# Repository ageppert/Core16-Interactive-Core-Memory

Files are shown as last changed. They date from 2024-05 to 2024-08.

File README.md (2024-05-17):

# Core-16-Interactive-Core-Memory-Badge
Weave your own 16 bits of core memory over the top of LEDs to interact with directly using a magnetic wand. This project shares the same codebase as Core64. 

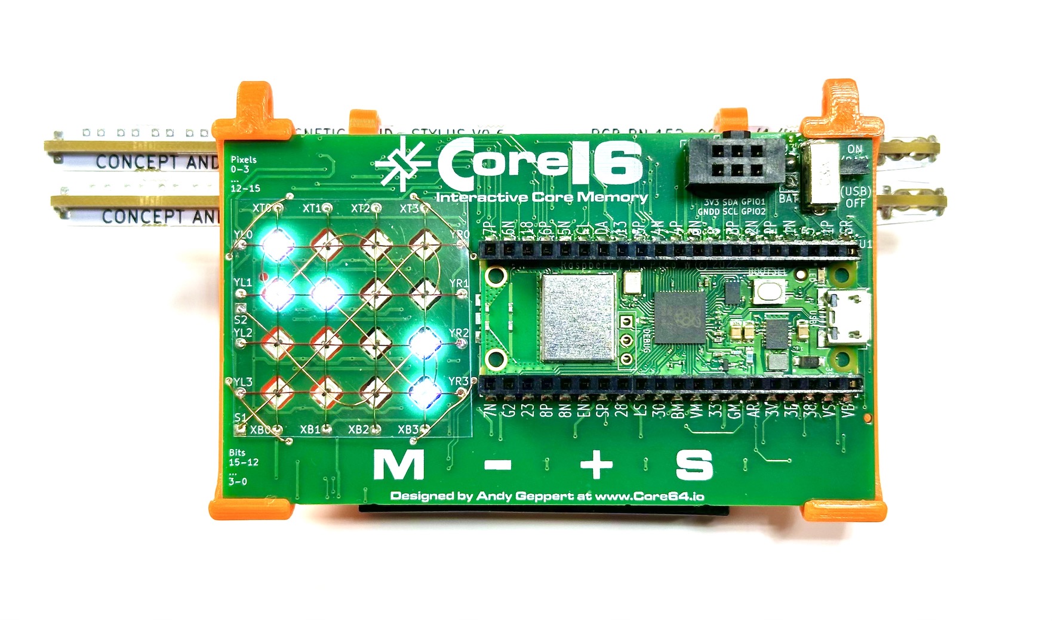
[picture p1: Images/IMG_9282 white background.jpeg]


Purchase: https://www.Core64.io

Follow this project at: https://hackaday.io/project/191834-core16-interactive-core-memory-made-smaller

You are in the hardware development repository. Firmware is at https://github.com/ageppert/Core64/releases

# Hardware Version History (latest on top)

v0.2 Logic Board - First production batch

v0.1 Logic Board - Prototype Build

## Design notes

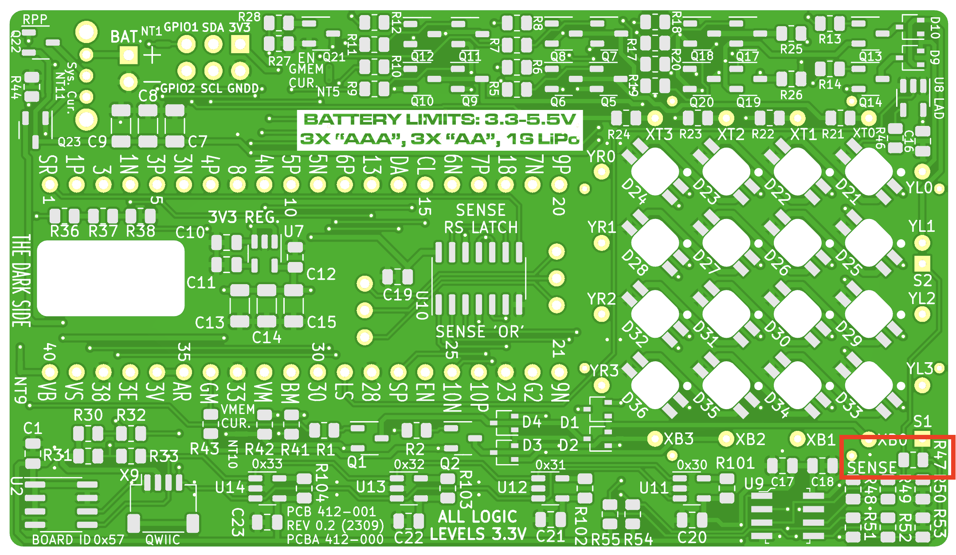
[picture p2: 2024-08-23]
Electronic Design/Core16_LB_V0.2 Schematic and Renders/Core16_LB_V0.2_Render_Back R47.png

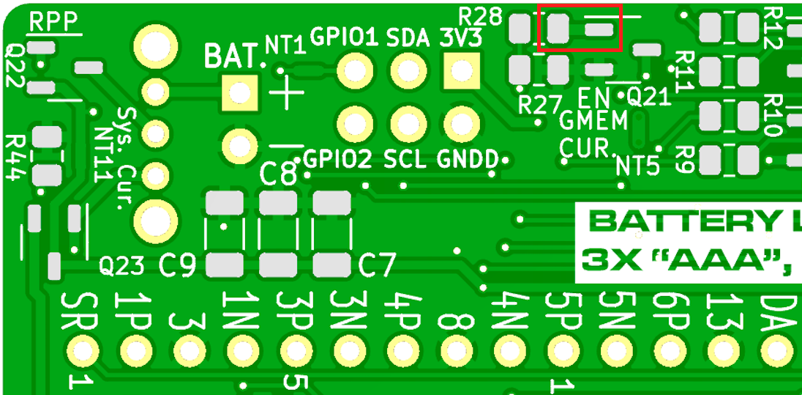
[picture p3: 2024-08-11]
Electronic Design/Core16_LB_V0.2 Schematic and Renders/CM_EN Q21 R28.png

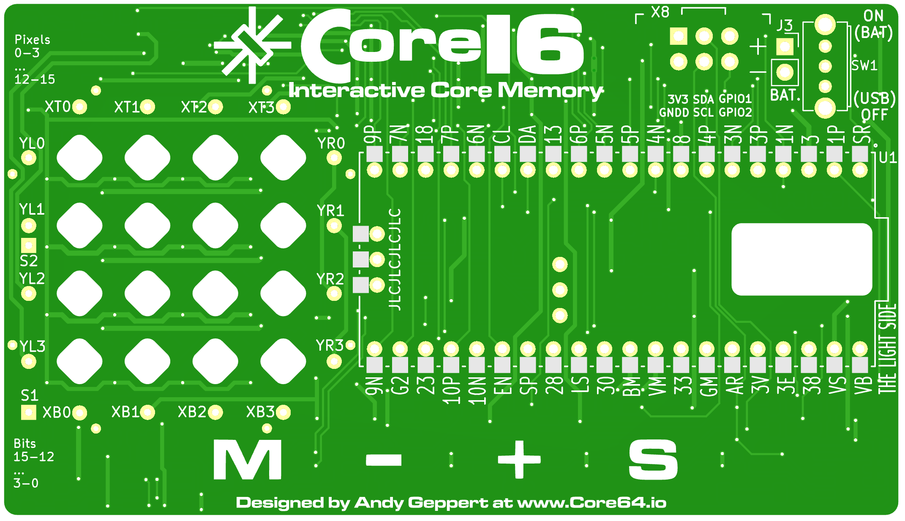
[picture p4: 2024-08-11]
Electronic Design/Core16_LB_V0.2 Schematic and Renders/Core16_LB_V0.2_Render_Front.png

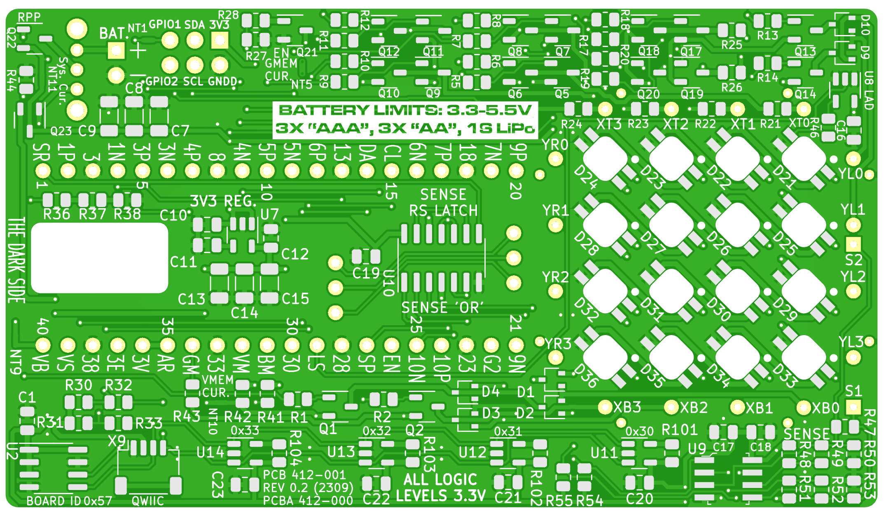
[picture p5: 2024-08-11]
Electronic Design/Core16_LB_V0.2 Schematic and Renders/Core16_LB_V0.2_Render_Back.png

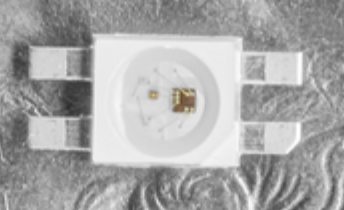
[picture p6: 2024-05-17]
Datasheets/LED REV MOUNT SK6812 light side.png

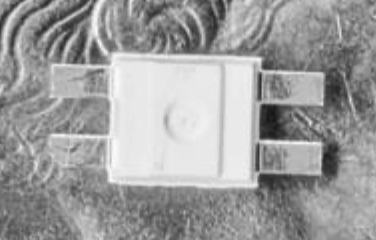
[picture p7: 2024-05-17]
Datasheets/LED REV MOUNT SK6812 dark side.png

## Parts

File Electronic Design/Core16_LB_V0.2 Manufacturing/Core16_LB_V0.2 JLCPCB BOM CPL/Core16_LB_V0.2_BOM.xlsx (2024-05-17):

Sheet: Core16_LB_BOM
Line | Description | Designators | Package | Qty | Manufacturer | MPN | Notes | Substitute | Customer Provided? | Vendor | Vendor PN | Manufacturer(Secondary) | MPN(Secondary) | VENDOR (SECONDARY) | VEMDOR P/N (SECONDARY)
1 | Capacitor 0805 0.1uF | C1, C16, C17, C19-C23 | 0805 | 8 | Cheaper to buy 1000 |  | Prefer X7R, X5R OK too. | YES | NO
2 | Capacitor 1206 220uF | C7-C9, C13-C15 | 1206 | 6 |  |  | Prefer X7R, X5R OK too. | YES | NO
3 | Capacitor 0805 1uF | C10, C12 | 0805 | 2 |  |  | Prefer X7R, X5R OK too. | YES | NO
4 | Capacitor 0805 0.01uF | C11 | 0805 | 1 |  |  | Prefer X7R, X5R OK too. | YES | NO
5 | Capacitor 0805 10uF | C18 | 0805 | 1 |  |  | Prefer X7R, X5R OK too. | YES | NO
6 | DIODE ARRAY SCHOTTKY 30V BAT54CW | D1, D3, D9 | SOT-323 | 3 | Diodes Inc. | BAT54CW-7-F |  | NO | NO | DIGI-KEY | BAT54CW-FDITR-ND
7 | DIODE ARRAY SCHOTTKY 30V BAT54AW | D2, D4, D10 | SOT-323 | 3 | Diodes Inc. | BAT54AW-7-F |  | NO | NO | DIGI-KEY | BAT54AW-FDITR-ND
8 | NEOPIXEL REVERSE MOUNT RGB LED SK6812 | D21-D36 | 3.10mm L x 2.70mm W | 16 | DONGGUAN OPSCO OPTOELECTRONICS | SK6812-E | EEK. Just one manufacturer I know of! Sold through Digi-Key, Mouser, and Adafruit. | NO | NO | DIGI-KEY | 1528-4960-ND |  |  | MOUSER | 485-4960
9 | TRANS MMBT4403LT1G PNP 40V 0.6A SOT23 | Q1, Q5, Q7, Q9, Q11, Q13, Q17, Q19 | SOT-23 | 8 | ON Semiconductor | MMBT4403LT1G | Cheaper to buy 1000 | NO | NO | DIGI-KEY | MMBT4403LT1GOSCT-ND | Diodes Inc. | MMBT4403-7-F
10 | TRANS MMBT4401LT1G NPN 40V 0.6A SOT23 | Q2, Q6, Q8, Q10, Q12, Q14, Q18, Q20 | SOT-23 | 8 | ON Semiconductor | MMBT4401LT1G | Cheaper to buy 1000 | NO | NO | DIGI-KEY | MMBT4401LT1GOSCT-ND | Diodes Inc. | MMBT4401-7-F
11 | MOSFET NVTR4503NT1G_NMOS_GSD N-CHNL GSD LOW RDS(ON) | Q21 | SOT-23 | 1 | ON Semiconductor | NVTR4503NT1G |  | NO | NO | DIGI-KEY | NVTR4503NT1GOSTR-ND | Infineon Technologies | IRLML2030TRPBF
12 | MOSFET SL3401A P-Channel 30V 4.2A 2V @ 250uA 50mŒ© @ 4.2A,10V 1.4W SOT-23 | Q22, Q23 | SOT-23 | 2 | Micro Commercial Co | SL3401A-TP |  | NO | NO | DIGI-KEY | 353-SL3401A-TPTR-ND
13 | RES 470 OHM 10% | R1, R2, R5-R14, R17-R20, R28, R46 | 0805 | 18 |  |  | Any as long as tolerance matched or better | YES | NO
14 | RES 6.8 OHM 1/8W 5% | R21-R26 | 0805 | 6 |  |  | Any as long as tolerance matched or better | YES | NO
15 | RES 10K OHM 10% | R27, R36-R38, R44, R101-R104 | 0805 | 9 | Cheaper to buy 1000 |  | Any as long as tolerance matched or better | YES | NO
16 | RES 1.2K OHM 10% | R30, R31, R54, R55 | 0805 | 4 |  |  | Any as long as tolerance matched or better | YES | NO
17 | RES 68 OHM 10% | R32, R33 | 0805 | 2 |  |  | Any as long as tolerance matched or better | YES | NO
18 | RES 10K OHM 10% | R41-R43 | 0805 | 3 |  |  | Any as long as tolerance matched or better | YES | NO
19 | RES 1.5K OHM 1% | R50, R53 | 0805 | 2 |  |  | Any as long as tolerance matched or better | YES | NO
20 | RES 1.8K OHM 1% | R48, R51 | 0805 | 2 |  |  | Any as long as tolerance matched or better | YES | NO
21 | RES 11 OHM 1% | R49, R52 | 0805 | 2 |  |  | Any as long as tolerance matched or better | YES | NO
22 | IC EEPROM M24C02-RMN 2KBIT I2C 400KHZ 8SOIC | U2 | 8-SOIC | 1 | STMicroelectronics | M24C02-WMN6TP |  | NO | NO | DIGI-KEY | 497-8552-2-ND
23 | Fixed 3.3V 300mV @ 300mA SOT-23-5 Dropout Regulators(LDO) RoHS | U7 | SOT23-5 | 1 | SG Micro | SGM2007-3.3XN5_TR |  | NO | NO | DIGI-KEY | 296-TPS7A0533PDBVRTR-ND | TI | TPS7A0533PDBVR
24 | IC BUF NON-INVERT 5.5V SOT23-5 | U8 | SOT23-5 | 1 | Texas Instruments | SN74LV1T125DBVR |  | NO | NO | DIGI-KEY | 296-37172-2-ND | OnSemi | M74VHC1GT125DT1G
25 | IC COMPARATOR LM393 LP DUAL 8-SOIC | U9 | 8-SOIC | 1 | STMicroelectronics | LM393DT |  | NO | NO | DIGI-KEY | 497-1593-2-ND | Rohm | LM393DR
26 | IC GATE SN74HC02DR NOR 4CH 2-INP 14SOIC | U10 | 14-SOIC | 1 | Texas Instruments | SN74HC02DR |  | NO | NO | DIGI-KEY | 296-1188-2-ND
27 | Si7210 Series I2C Hall Effect Magnetic Position and Temperature Sensor 1 | U11 | SOT23-5 | 1 | Silicon Labs | SI7210-B-00-IV | Similar to the others, but has specific I2C bus address | NO | NO | DIGI-KEY | 336-4068-ND
28 | Si7210 Series I2C Hall Effect Magnetic Position and Temperature Sensor 2 | U12 | SOT23-5 | 1 | Silicon Labs | SI7210-B-02-IV | Similar to the others, but has specific I2C bus address | NO | NO | DIGI-KEY | 336-SI7210-B-02-IV-ND
29 | Si7210 Series I2C Hall Effect Magnetic Position and Temperature Sensor 3 | U13 | SOT23-5 | 1 | Silicon Labs | SI7210-B-03-IV | Similar to the others, but has specific I2C bus address | NO | NO | DIGI-KEY | 336-SI7210-B-03-IV-ND
30 | Si7210 Series I2C Hall Effect Magnetic Position and Temperature Sensor 4 | U14 | SOT23-5 | 1 | Silicon Labs | SI7210-B-04-IV | Similar to the others, but has specific I2C bus address | NO | NO | DIGI-KEY | 336-4056-ND
31 | JST_SH_SM04B-SRSS-TB_1x04 QWIIC Connector right angle | X9 | SM04B-SRSS-TB | 1 | JST | SM04B-SRSS-TB | Not on Mouser, digi only | NO | NO | DIGI-KEY | 455-SM04B-SRSS-TBTR-ND
 |  | Need 5 more sk6812-E |  | 117

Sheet: Sheet1
Part # | Mouser # | Mfr. # | Manufacturer | Description | Order Qty. | Price (USD) | Ext.: (USD)
C1, C16, C17, C19-C23 | 187-CL21B104KAFNNNE | CL21B104KAFNNNE | Samsung Electro-Mechanics | Multilayer Ceramic Capacitors MLCC - SMD/SMT 100nF+/-10% 25V X7R 0805 | 805 | $0.009 | $7.24
C10, C12 | 187-CL21B105KAFNNNE | CL21B105KAFNNNE | Samsung Electro-Mechanics | Multilayer Ceramic Capacitors MLCC - SMD/SMT 1uF+/-10% 25V X7R 20 0805 | 205 | $0.021 | $4.31
C18 | 187-CL21B106KOQNNNG | CL21B106KOQNNNG | Samsung Electro-Mechanics | Multilayer Ceramic Capacitors MLCC - SMD/SMT 10uF+/-10% 16V X7R 2 0805 | 105 | $0.061 | $6.41
D1, D3, D9 | 621-BAT54CW-F | BAT54CW-7-F | Diodes Incorporated | Schottky Diodes & Rectifiers 30V 200mW | 301 | $0.098 | $29.50
D2, D4, D10 | 621-BAT54AW-F | BAT54AW-7-F | Diodes Incorporated | Schottky Diodes & Rectifiers 30V 200mW | 301 | $0.106 | $31.91
D21-D36 | 485-4960 | 4960 | Adafruit | Adafruit Accessories NeoPixel Reverse Mount RGB LEDs - 10 Pack of SK6812-E | 140 | $2.95 | $413.00
Q1, Q5, Q7, Q9, Q11, Q13, Q17, Q19 | 863-MMBT4403LT1G | MMBT4403LT1G | onsemi | Bipolar Transistors - BJT 600mA 40V PNP | 1002 | $0.03 | $30.06
Q2, Q6, Q8, Q10, Q12, Q14, Q18, Q20 | 863-MMBT4401LT1G | MMBT4401LT1G | onsemi | Bipolar Transistors - BJT 600mA 60V NPN | 1002 | $0.032 | $32.06
Q21 | 863-NVTR4503NT1G | NVTR4503NT1G | onsemi | MOSFET Single N-Channel Power MOSFET 30V, 2.5A, 110mohm Automotive Version of the NTR4503N | 101 | $0.183 | $18.48
Q22, Q23 | 833-SL3401A-TP | SL3401A-TP | Micro Commercial Components (MCC) | Schottky Diodes & Rectifiers P-Ch -30V 12Vgs 1.5W -4.4A | 202 | $0.186 | $37.57
R1, R2, R5-R14, R17-R20, R28, R46 | 660-RK73H2ATTD4700F | RK73H2ATTD4700F | KOA Speer | Thick Film Resistors - SMD 1/4W 470 OHM 1% | 1810 | $0.007 | $12.67
R21-R26 | 660-RK73H2ATTD6R80F | RK73H2ATTD6R80F | KOA Speer | Thick Film Resistors - SMD 1/4W 6.8 OHM 1% | 610 | $0.011 | $6.71
R27, R36-R38, R44, R101-R104 | 660-RK73H2ATTD1002F | RK73H2ATTD1002F | KOA Speer | Thick Film Resistors - SMD 1/4W 10K OHM 1% | 910 | $0.007 | $6.37
R30, R31, R41-R43, R54, R55 | 660-RK73H2ATTD1201F | RK73H2ATTD1201F | KOA Speer | Thick Film Resistors - SMD 1/4W 1.2K OHM 1% | 710 | $0.01 | $7.10
R32, R33 | 660-RK73H2ATTD68R0F | RK73H2ATTD68R0F | KOA Speer | Thick Film Resistors - SMD 1/4W 68 OHM 1% | 205 | $0.01 | $2.05
R48, R51 | 660-RK73H2ATTD1801F | RK73H2ATTD1801F | KOA Speer | Thick Film Resistors - SMD 1/4W 1.8K OHM 1% | 205 | $0.01 | $2.05
R49, R52 | 660-RK73H2ATTD11R0F | RK73H2ATTD11R0F | KOA Speer | Thick Film Resistors - SMD 1/4W 11 OHM 1% | 205 | $0.01 | $2.05
R50, R53 | 660-RK73H2ATTD1501F | RK73H2ATTD1501F | KOA Speer | Thick Film Resistors - SMD 1/4W 1.5K OHM 1% | 205 | $0.01 | $2.05
U10 | 595-SN74HC02DR | SN74HC02DR | Texas Instruments | Logic Gates Quad 2-Input | 101 | $0.194 | $19.59
U11 | 634-SI7210-B-00-IVR | Si7210-B-00-IVR | Silicon Laboratories | Board Mount Hall Effect / Magnetic Sensors I2C programmable Hall effect magnetic sensor with push-pull output | 101 | $1.01 | $102.01
U12 | 634-SI7210-B-02-IV | Si7210-B-02-IV | Silicon Laboratories | Board Mount Hall Effect / Magnetic Sensors I2C programmable Hall effect magnetic sensor with push-pull output | 101 | $0.901 | $91.00
U13 | 634-SI7210-B-03-IV | Si7210-B-03-IV | Silicon Laboratories | Board Mount Hall Effect / Magnetic Sensors I2C programmable Hall effect magnetic sensor with push-pull output | 101 | $0.806 | $81.41
U14 | 634-SI7210-B-04-IVR | Si7210-B-04-IVR | Silicon Laboratories | Board Mount Hall Effect / Magnetic Sensors I2C programmable Hall effect magnetic sensor with push-pull output | 101 | $0.828 | $83.63
U2 | 511-M24C02-WMN6TP | M24C02-WMN6TP | STMicroelectronics | EEPROM EEPROM S I2C 2K | 101 | $0.133 | $13.43
U8 | 595-SN74LV1T125DBVR | SN74LV1T125DBVR | Texas Instruments | Translation - Voltage Levels SGL Pwr Supply SGL Buffer GATE | 101 | $0.316 | $31.92
U9 | 511-LM393DT | LM393DT | STMicroelectronics | Analog Comparators Lo-Pwr Dual Voltage SOIC-8 | 101 | $0.268 | $27.07
U7 | 595-TLV75533PDBVR | TLV75533PDBVR | Texas Instruments | IC REG LINEAR 3.3V 500MA SOT23-5 | 101 | $0.201 | $20.30
 | Digi #
C7-C9, C13-C15 | 490-GRM31CR60J227ME11KCT-ND | GRM31CR60J227ME11K | Murata Electronics | CAP CER 220UF 6.3V X5R 1206 | 605 | $0.343 | $207.21
D21-D36 | 1528-4960-ND | 4960 | Ada Fruit | NeoPixel | 15 | $2.950 | $44.25
X9 | 455-SM04B-SRSS-TBTR-ND | SM04B-SRSS-TBTR-ND |  | JST_SH_SM04B-SRSS-TB_1x04 QWIIC Connector right angle | 100 | $0.427 | $42.66
 |  |  |  |  |  |  | $1416.08
 |  |  |  | I always buy a few extra parts for caps, etc in case one is damaged, or flies into oblivion during construction. :-)
 |  |  |  | Will still need 50 more neopixels from Ada, or other source
 |  |  |  | This price doesn't include shipping or tax from Digi, just the parts for the moment.
 |  |  |  | Still missing the regulator too.
 |  |  |  | Andy's Notes updating V0.1 to V0.2 BOM
 |  |  |  | Added U7 3V3 REG as the TI part you suggested up in the Mouser section. Removed from Digikey.
 |  |  |  | Removed C11 since it is not needed with the new TI Regulator.
 |  |  |  | Corrected R21-26 from 6.8K to 6.8 OHM
 |  |  |  | Move R41-43 out of the group in the line above (10K) to 1K2, corrected quantities on both lines
 |  |  |  | Corrected C1, C16, C17, C19-C23 (8x) quantity from 1010 to 805

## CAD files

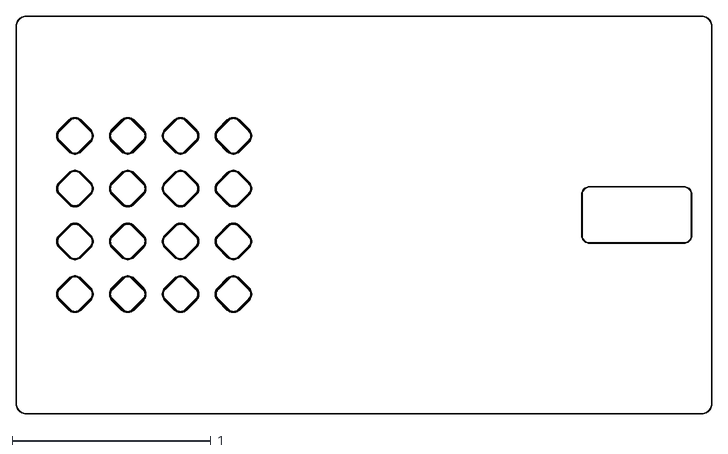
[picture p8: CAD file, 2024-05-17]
Electronic Design/Core16_LB_V0.2 Manufacturing/Core16_LB-Edge_Cuts.dxf
3.50 x 2.00

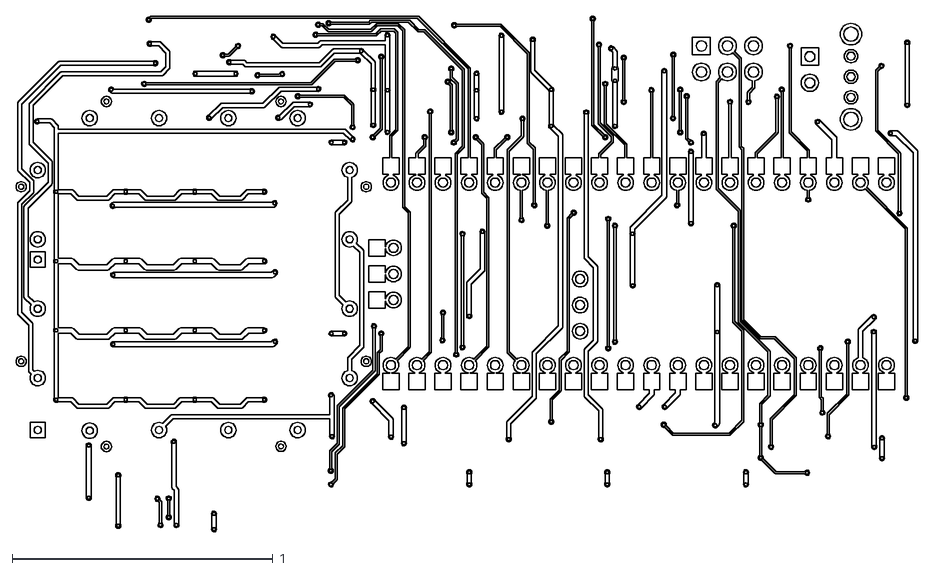
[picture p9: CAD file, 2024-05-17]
Electronic Design/Core16_LB_V0.2 Manufacturing/Core16_LB-F_Cu.dxf
3.46 x 1.98

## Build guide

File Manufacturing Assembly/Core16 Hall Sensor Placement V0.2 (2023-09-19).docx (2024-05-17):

Core16 Hall Sensor Placement V0.2 (2023-09-19)

The hall sensors are installed on the Back Side (AKA The Dark Side). Each one has only one position it can be in to work correctly because they all have unique I2C IDs. Once they are removed from the packaging you can no longer identify which is which.

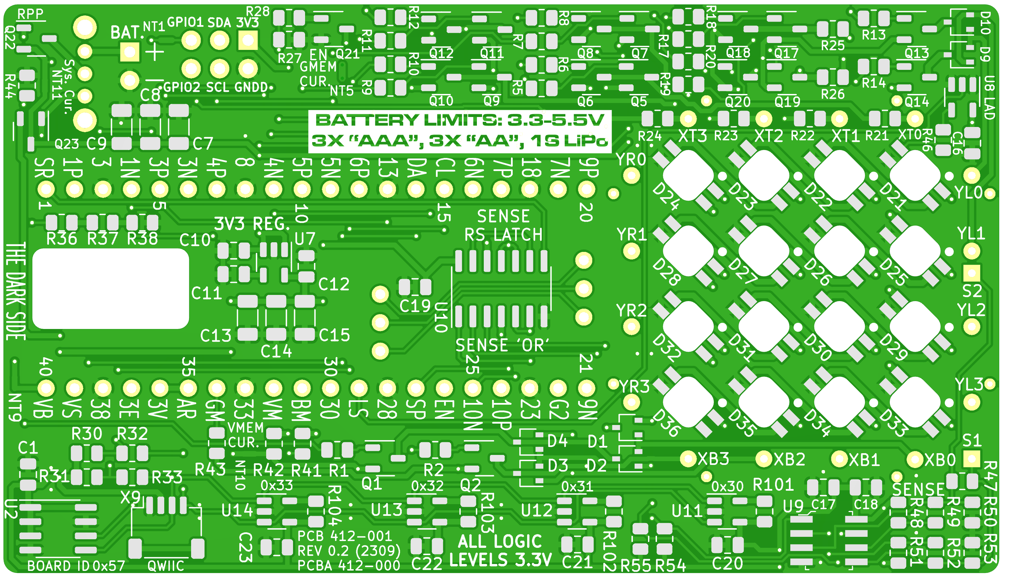
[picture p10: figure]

S + - M

4 3 2 1

P/N SI7210-B- -04 -03 -02 -00

For reference, this is the Front Side (AKA The Light Side)

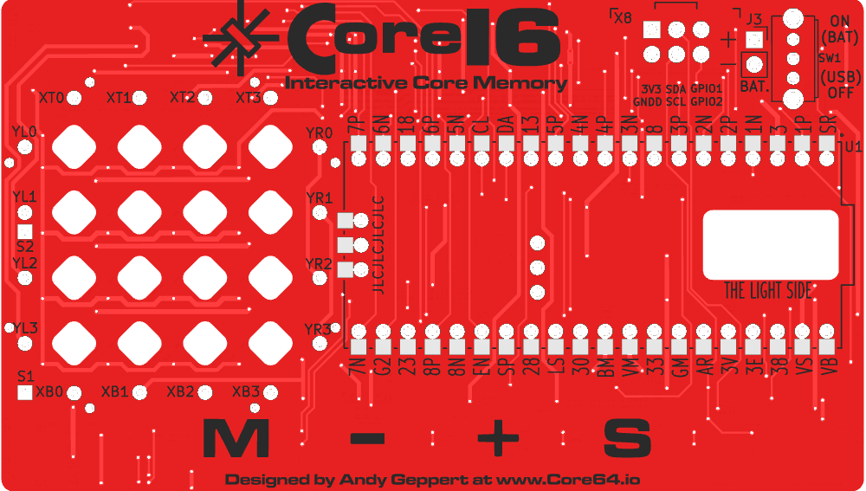
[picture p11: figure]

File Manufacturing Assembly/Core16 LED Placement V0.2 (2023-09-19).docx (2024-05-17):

Core16 LED Placement V0.2 (2023-09-19)

SK6812Mini-E LEDs are installed on the Back Side (AKA The Dark Side)

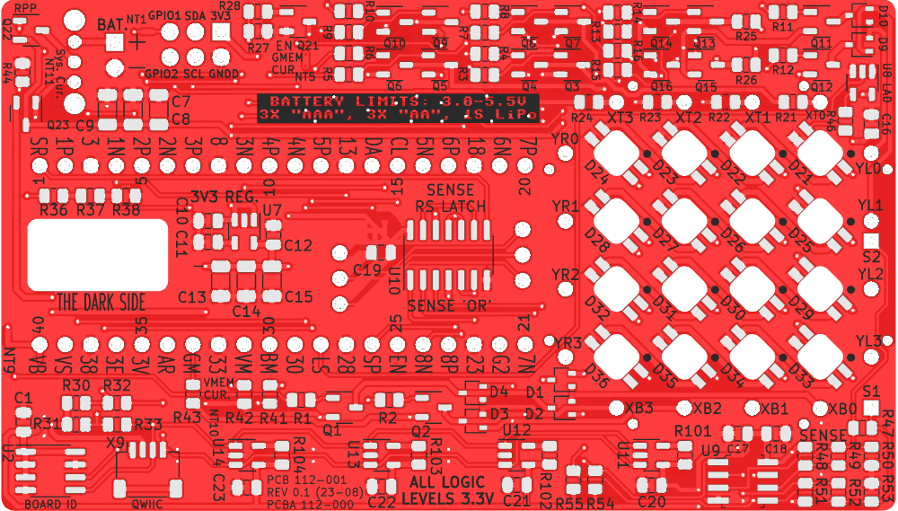
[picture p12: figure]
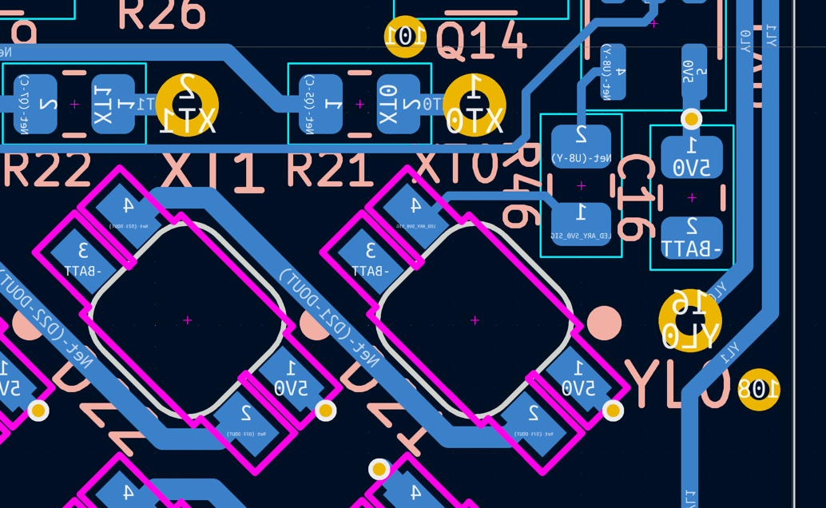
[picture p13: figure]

DOUT

DIN

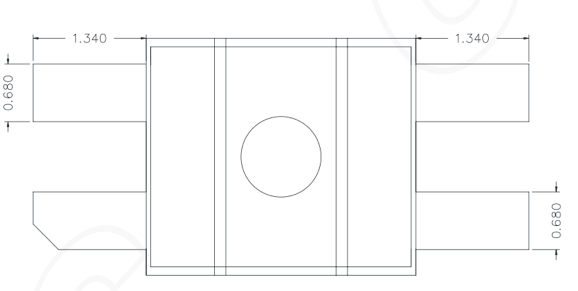
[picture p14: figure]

5V0

GND

CENTERED IN THE CUTOUT

These LEDs are serially connected which means if any LED in the chain is missing or damaged, all the LEDs downstream will not work. When testing the assembly process, always start with D21.

For reference, this is how they look on the Front Side (AKA The Light Side)

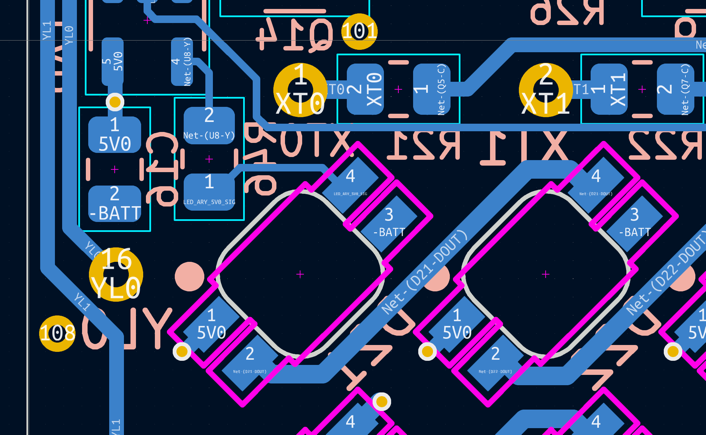
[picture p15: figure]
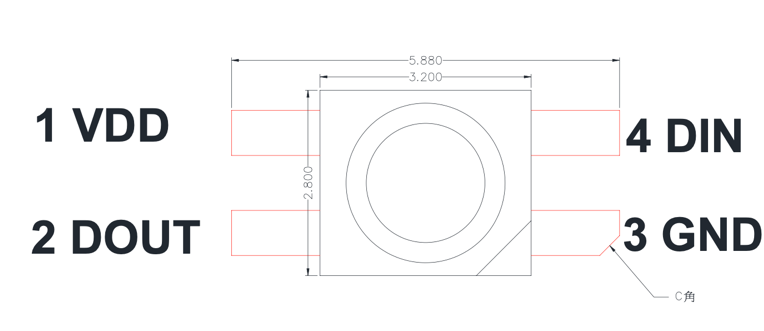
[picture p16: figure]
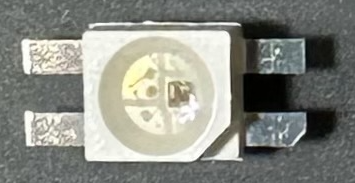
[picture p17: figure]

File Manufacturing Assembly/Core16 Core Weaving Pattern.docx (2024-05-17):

Core16 Core Weaving Pattern (2023-10-08)

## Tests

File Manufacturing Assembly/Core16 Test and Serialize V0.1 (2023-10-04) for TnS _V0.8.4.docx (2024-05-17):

Core16 Test and Serialize

Document V0.1 (2023-10-04) goes with firmware “Core16_TnS _V0.8.4.uf2”

Program the Raspberry Pi Pico with latest Test and Serialize (TnS) firmware. See Appendix A.

(1) Write Serial Number with thin sharpie or sticker on the back of the Core16 Logic Board.

OK to use last 3 digits only. Write between U7 and U10. This batch of 100 starts at S/N 300006 and goes to 300105.

(2) Program the Core16 Board ID EEPROM with the Serial Number

Start with power off, clamp Core16 Logic Board in the test fixture, power on.

Connect with Serial Terminal at 115200 8N1. LEDs may flash brightly.

Start-up sequence determines if Board ID EEPROM is present and blank.

CORE16: Use 's' command to set last three digits of 300xxx serial number.

Examples: S 6<ENTER> or S 105<ENTER>

Core16 restarts immediately after a valid entry.

(3) Verify I2C Bus Devices are present and

I2C Bus Scan results

Verify I2C SCAN 5 items are present:

Device found at address 0x30 (SI7210-B-01, Hall Sensor 1)

Device found at address 0x31 (SI7210-B-02, Hall Sensor 2)

Device found at address 0x32 (SI7210-B-03, Hall Sensor 3)

Device found at address 0x33 (SI7210-B-04, Hall Sensor 4)

Device found at address 0x57 (EEPROM BOARD ID)

Depending on the test fixture configuration, there may also be another device if the OLED is connected:

Device found at address 0x3C (SSD1306,DigisparkOLED)

(4) Verify power supply is good

INFO DISPLAY: Verify INFO section voltages 5V0 Rail = 5.0 ± 0.3 and 3V3 Rail = 3.3 ± 0.1

(5) Test Core Memory Matrix Driver Circuitry

NOT AVAILABLE IN SIMPLE TEST FIXTURE WHEN CORES ARE NOT INSTALLED.

If S/N is >= 300006, it will automatically jump to MODE_CORE_TEST_MANY (#31)

Use the magnetic stylus on the core memory to make sure all pixels respond by lighting up.

(6) Test Hall Sensors

Touch + with stylus to move to next mode, MODE_HALL_TEST (#32)

Verify one LED lights for each magnetic button. With each stylus touch of magnetic button, one of the four corresponding lower row LEDs will illuminate.

(7) Test LEDs

Dwell 2 seconds on “+” magnetic button to go to next MODE_LED_TEST_ALL_RGB (#33).

Verify all LEDs are illuminated in RED, GREEN, BLUE sequence.

Power off and remove Core16 from test fixture.

END OF TEST

# APPENDIX A: PROGRAMMING A PICO

Program the Raspberry Pi Pico with latest Test and Serialize (TnS) firmware

Start with power off.

Hold button on Pico, connect Pico USB to computer, release button.

Pico enumerates as Mass Storage device. RPI-RP2 or similar.

Open Mass Storage device and drag-n-drop “Core16_TnS _V0.8.4.uf2” into first level.

File copies over, Mass Storage device disappears, Pico restarts and runs the new firmware.

In normal operation, the Pico LED blinks in heartbeat pattern when powered on and streams information through serial port.

End with power off.

# APPENDIX B: IMPLEMENTATION NOTES

case MODE_START_EEPROM

If LogicBoardTypeGet returns UNKNOWN, set MODE_MANUFACTURING_EEPROM_FACTORY_WRITE and break right before LED and Buttons are set-up.

case MODE_START_SEQUENCE_COMPLETE

If LogicBoardTypeGet is Core16 and S/N is between 300004 and 300105,

One more INFO so it’s close to the bottom of the screen.

Change Mode to MODE_CORE_TEST_MANY

case MODE_MANUFACTURING_EEPROM_FACTORY_WRITE

Serial interaction:

Mfg mode splash

Core16 expecting S/N 300006 to 300105.

Request last three digits of S/N.

Add Command Line Handler for undocumented command “S” followed by a number.

The largest value that can be handled with atoi is 65535.

Verify between 6 and 105.

Convert that number back to STRING of three characters to write to EEPROM.

Write everything to EEPROM.

INFO

Prompt user “is it correct Y/N?”

If yes, Set mode to MODE_START_POWER_ON

If no, ask for last 3 digits

If S/N 300001 to 300005 then HWV = 0.1.0 and manufacturer is JLCPCB.

If S/N 300006 to 300105 then HWV = 0.2.0 and manufacturer is TexElec.

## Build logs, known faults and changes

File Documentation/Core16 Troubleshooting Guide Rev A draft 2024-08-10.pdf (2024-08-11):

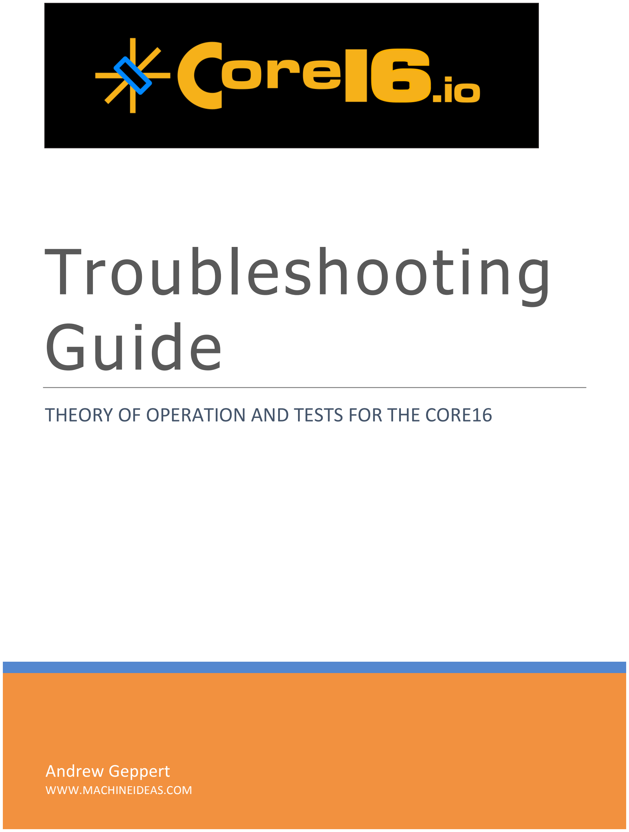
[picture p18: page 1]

# Andrew Geppert

### WWW.MACHINEIDEAS.COM

# Troubleshooting Guide

# THEORY OF OPERATION AND TESTS FOR THE CORE16

Core16 Troubleshooting Guide | www.Core16.io | 2

## 1. TABLE OF CONTENTS

## 2. Version History of This Guide

Revision | Description | Author | Date
A | First draft | Andy Geppert | 2024-08-10

The project homepage for this product is at www.Core16.io, which may still point to www.Core64.io.
The latest version of documentation is at https://github.com/ageppert/Core16-Interactive-Core-Memory.
The latest version of firmware is shared with Core64 and Core64c at https://github.com/ageppert/Core64/releases. Concept and design by Andy Geppert at www.MachineIdeas.com.

## 3. Important Cautions and Warnings

Beware the ESD monster!

Pico refers the Raspberry Pi Pico or Pico W which is should have all 40 castellated vias solder to the Core16 Logic Board.

Logic Board refers to the Core16 Logic Board.

Oscilloscope voltages are generally not accurate and have a surprising amount of error tolerance compared to a good multimeter. Oscilloscope voltages are more for reference and looking at signal shapes. Don’t be thrown off if a normal voltage is listed in the documentation here, and your scope is off by several tenths of a volt. Similarly, how much do you trust your multimeter? Just keep this general advice in mind and don’t get too hung up on voltage level accuracy.

Continuity checks should be done with a good multimeter. Press the probe tips into the solder joint to get through the cruft.

Use flux for soldering, but also, clean it off when you are done soldering.

These caution symbols point out important things to help ensure your assembly goes smoothly!

## 4. Introduction

This guide steps through the functionality of the Logic Board for Core16. Each functional section is reviewed, in sequence form power on through full operation of all cores and associated LEDs.

You do not need to proceed through the guide in sequence. Use your intuition to jump in where you think it makes sense. For instance, if you are confident you have power and the correct firmware installed, and the LEDs always on but unresponsive to the magnetic stylus, jump to the section “Core Matrix Row and Column Drivers.”

Since each of the Core16 Logic Boards go through a complete functional test before shipping to customers, the most likely problem areas are where the customer completes final assembly steps. In order of most frequent to least frequent:
- Core Matrix solder joints
- Core Sense Wire solder joints
- Core weaving pattern
- Solder connections between the Pico castellated vias and the Logic Board
- Battery and power switch connections
- Stylus magnetism weak due to excessive soldering heat

Carefully check all of those items to make sure they are all done well, and all connections that you made have good continuity.

Still, it could be that something has been damaged elsewhere on the Logic Board. Perhaps by mishandling, or damaging components adjacent to the outer edges of the Logic Board, or around the perimeter of the Core Matrix area. Visually inspect those areas carefully.

When installing the Core16 into the plastic carrier frame, insert the left edge of the board by sliding it into the plastic clips on the left. Then carefully snap the right edge plastic clips up around the right edge of the board. The reasoning is that the components on the back-side of the left edge/corners of the board are more fragile than the ones on the right edge/corners.

When removing the Core16 from the plastic carrier frame, carefully un-snap the right edge first. Then slide the left edge out of the plastic clips.

The following sections are organized in the functional sequence of the Core16 system. That is:
- Power Supply
- Microcontroller – the Pico W
- Serial Port
- I2C Bus Interface
- EEPROM for Board ID
- Info Query
- Core Matrix Wiring – the part you complete, which is the most likely source of issues
- Core Matrix Enable
- Core Matrix Row and Column Drivers
- Core Signal Sense
- Core Signal Output Latch
- Magnetic Stylus
- RGB LEDs
- Hall Sensors
- SAO OLED (optional)
- SAO and QWIIC ports (optional accessories)

## 5. Theory of Operation

All modes of operation with the Cores, LEDs and Magnetic Stylus are similar. Each Core in the matrix is written to with a pulsed electromagnetic field created along the length of the row and column wires. Where the two address wires intersect the core, the combined (aka coincident) magnetic field is strong enough to magnetize the wire in a clockwise or counter-clockwise orientation. Each orientation is defined as 1 or 0. If the orientation has been changed by the magnetic field created in the address wires, a small voltage will be induced into the sense wire. That voltage is detected by differential op-amps in the sense circuit, and latched into simple dual-NOR gate latch. If this occurs, the firmware detects that the core state was changed, the core will then be reset to the opposite state, and the firmware reports the value of that core bit. This information is used to illuminate the corresponding LED when the core is set to 1, or extinguish the LED if the core is 0.

## 6. Schematic and PCB Layout

Reference: https://github.com/ageppert/Core16-Interactive-Core-Memory/tree/master/Electronic%20Design/Core16_LB_V0.2%20Schematic%20and%20Renders

Schematic
The schematic is organized into functional sections which correspond to the sections of this guide.

PCB Layout
The PCB layout is fairly tight, and doesn’t follow the schematic blocks perfectly, but it attempts to lump functional elements together in the same area.
TO DO: Block diagram sections of schematic connected to rendering of the back of the board to make navigation easier.

## 7. Symptoms and Test Table

Failure Symptoms and likely causes
If all of the LEDs are on, there is a problem common to the whole matrix. The sense wire and circuit are common to the whole matrix.
The core memory enable CM_EN signal is common to the whole matrix.
Overview
After power on, the 4x4 matrix of LEDs should show three symbols in a row, in RED: C, 16, and the hysteresis flux symbol.
Then it will move to scrolling text “I [heart] CORE16”.
After that that, several more multicolor symbols will be displayed and it will return to scrolling text.

During scrolling text, the cores are actually being used as screen RAM. Interaction with the magnetic stylus should alter the state of the LEDs in the scrolling text mode.

In the other mode, displaying symbols, the cores are NOT being used, and just the LEDs are being controlled.

Beginning with the power sources. The Core16 may be powered from a battery pack or micro USB cable. To

SYMPTOM | TEST STARTING POINT | ASSUMPTIONS
Nothing happens when I connect the USB Cable. | Power Supply | No power.
All I see is an Green LED blinking on the Pico W. | | No firmware.

The serial port responds, but nothing shows on the RGB LEDs

Some symbols displayed correctly, but instead of scrolling text, all LEDs are on, fading through a rainbow of colors. None of the cores/LEDs respond to the magnetic stylus in any mode. | Info Query, and subsequent sections. | Power from USB is good. Firmware is installed. Serial connection established

## 8. Power Supply

Quick Test
With only USB power, switch in OFF (USB) position, ground at SAO port GND, verify
- 5.0V at VB pin 40 on Pico W (aka 5V_USB, PICO_VBUS)
- 4.9V at VS pin 39 on Pico W (aka PICO_VSYS)
- 3.3V at SAO port 3V3 pin
- 3.3V at U9 LM393 Dual Op-amp pin 8
- 3.3V at U10 74HC02 Quad NOR pin 14

Overview
Beginning with the power sources. The Core16 may be powered from a battery pack or micro USB cable. To simplify troubleshooting, use just the USB cable and leave the battery pack disconnected or remove the batteries. This will provide enough current to the Core16 Logic Board for troubleshooting, and enables serial communications for testing and diagnostics. Additionally, the computer USB ports are current limited.

For consistent troubleshooting, keep the USB cable connected, and enter mode 30 “SPECIAL/CORE TEST ONE.” The measurements included in the subsections below are made with the Core16 in this mode. Similar results are expected with the battery, but since you are troubleshooting the operation of the cores, you are unlikely to be able to navigate the menu with the cores/stylus. Thus, all testing is done with USB power.

Ground Reference for Measurements
Use the GND pin of the SAO port as your ground reference.

Battery Power on Back of Logic Board
The default configuration supports three “AAA” alkaline cells. Nominally, they supply 4.5V. Absolutely do not exceed 5.5V by trying something like a 2S LiPo. This will destroy the 3.3V Regulator.

If you suspect a short-circuit in the system, limit the current with a current limited power supply or resistor in series with the battery pack to the positive terminal of the Logic Board.

USB Power into Pico on Front of Logic Board
Connect the Pico to your computer with the MicroUSB cable. This supplies a clean 5V and it is conveniently current limited by the computer USB power manager. Unless there is something completely short-circuited on the Core16 Logic Board, the current limiting can be considered a nice feature.

The quality of USB cables varies significantly. The cable included in the kit has been tested to work well. Other cables may have excessive resistance, or by power only, without data signals. Make sure you are using a good USB cable with power AND data. Measure the voltage at the Pico connection to the Logic Board at Pin 40 labeled VB for VBUS. A range of 4.5 to 5.0V is normal.

It can be helpful to have a switched USB Hub between the computer and the Core16 so you can press a button to turn off the Core16 (to reset it) instead of unplugging the fragile Mico USB connection to the Core16. For example:

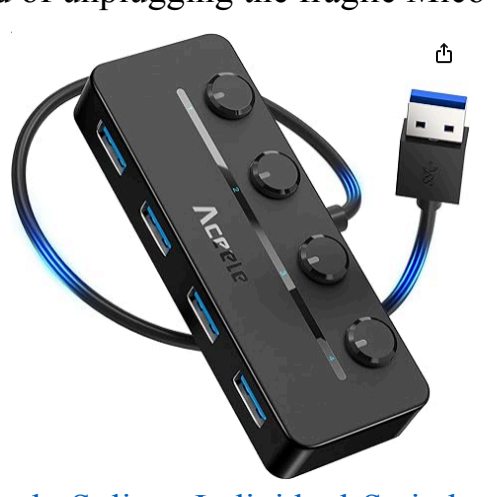
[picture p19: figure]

https://www.amazon.com/Aceele-Splitter-Individual-Switches-Portable/dp/B0CBTN686G/

Some USB hubs keep the serial connection (USB Data) connected and only interrupt the USB 5V power line.

Power Switch
The ON (BAT) position selects the battery as the source of power. It does NOT disconnect USB power if a USB cable is connected to the Pico because power is supplied downstream directly to the 5V0 rail of the Logic Board. The USB power bypasses the switch and reverse polarity protection circuit.

The OFF (USB) position selects the USB port as the source of power. It disconnects the battery power. If a USB cable is not connected, it effectively cuts all power to the Logic Board.

RPP - Reverse Polarity Protection
The protection is for the battery pack wires, which are soldered in near the power switch. If the wires are soldered into the wrong positions, or the battery cells are reversed, it prevents the Logic Board from receiving reverse polarity and protects it from damage.

+V Switched = 5V0
USED FOR:
- RGB LEDS
- 3V3 REGULATOR
This is a carry over from the Core64/c kits, which allow battery pack voltages greater than 5V, and include a 5V0 Regulator. In Core16, the voltage at this +VSW and 5V0 are equal, and will by 5V or less. Three capacitors are provided as bulk storage to smooth out power draw fluctuations from the RGB LEDs and the demands of the 3V3 Regulator. Despite the label of 5V0, the voltage will be between 3.5V and 5.0V normally.

3V3 Regulator
USED FOR:
- SYSTEM LOGIC
- CORE MATRIX DRIVER
- CORE MATRIX SENSE
- HALL SENSORS
- SAO AND QWIIC PORTS
The 3V3 Regulator creates a stable 3.3V source for all of the logic in the system, and the core memory.

Core Matrix Power
Three capacitors provide bulk storage to help hold up the 3V3 rail during the current surges used to write to the cores. Each row and column wire used to access a core is around 200-250 mA. When combined, this is a substantial 400-500mA draw on the 3V3 rail.

Core Matrix Enable
The Core Memory Enable CM_EN signal activates the Core Matrix FET which connects the entire Core Driver circuit GMEM to ground. This is used as a sort of a safety mechanism. During experimentation with firmware and control algorithms, you might inadvertently create a situation where the Core Matrix Drive Transistors are shorting the 3V3 to ground. By only activating CM_EN for a brief moment after the transistors are configured, this limits potential damage to the drive circuit. Generally, the 3V3 regulator save the components by kicking in a current limiting feature which will cause the 3V3 rail to fade to zero volts.

## 9. Microcontroller – Pico W Board

Overview
The Pico W can be operated independently from the Core16 Logic Board through the Micro USB port.

Factory fresh Pico’s and Pico W’s have pre-loaded firmware which blinks the built-in LED on the Pico at a 1 second interval. There will be no serial communication active with the default pre-loaded firmware.

If the Pico is programmed with the Core64/c/16 firmware (the same firmware is common to all three models) the built-in LED will blink in a heart beat pattern, and the serial port will periodically report the mode and respond to serial queries like “info” or “mode”.

At the time of this writing (Firmware Version 0.8.10), the Core16 Pico W uses the same firmware, but does NOT blink the built-in LED… because I haven’t gotten it working yet. It’s on the TO DO list.

Overview of Core16 operation with a magnetic stylus: https://www.youtube.com/watch?v=5HAyPMMNyDc

For more extensive information about the firmware operation, please refer to: https://github.com/ageppert/Core64/blob/master/Documentation
TO DO: Complete the User Guide and a video of the firmware walk-through.

PICO W Board Soldering
There are 40 castellated vias to solder to the Core16 Logic Board. Carefully inspect and verify continuity between the top of the Pico W thru-hole and the bottom of the Core16 Logic Board thru-hole.

Ensure firmware is installed
See the “Core64 Firmware Update Guide.pdf” to install firmware on the Core16. The firmware is common between Core64, Core64c, and Core16.

## 10. Microcontroller – Serial Port

Overview
The Pico W has a serial port, accessible through the Micro USB connection on the end of the Pico W. This used for diagnostics, changing modes, and changing settings.

Establish a serial connection
With the Micro USB cable connected to the Pico W, and the Pico W soldered down to the Logic Board, use your serial terminal of choice to establish a [115,200 8 bits, No Parity, 1 stop bit, no flow control] connection to the Pico W.

Ensure you are using a known good USB power AND DATA cable. Test it with another device to be sure.

Once the serial connection is established, send a RETURN from you keyboard to see the Core> command prompt.

Type “info” to capture information about your particular Core16. Don’t type the quotes. This is a helpful bit of information if you contact me about troubleshooting.

Type “mode 30” to enter the “Special/Core Test One” mode. This is the primary mode used for the tests in this guide. By default, the upper left core will be the single core to test. It is Pixel #0, and in this mode, is referenced as Core #0. To test other cores, type “cs [#]” where [#] is the Core # from 0 to 15.

Type “help” to see a list of commands.

Expected behavior
All LEDs in the matrix should be off.

When the magnetic stylus is placed over the upper left core, the LED should illuminate only when the stylus is present. Similar functionality for each individual core/LED, provided you use the “cs [#]” command to change the core under test.

## 11. I2C Bus Interface

Overview
An I2C Bus is fundamental to correct operation of the system. It is connected to:
- An EEPROM on the Logic Board with Board Specific Information on it, required for proper function of the firmware.
- Four magnetic hall sensors, under the M, -, +, and S symbols. These are “soft keys” used to select modes and change settings.
- Optionally, provide diagnostic information to a small 128x64 OLED I2C Display through the SAO port. I have these available on www.Core64.io and you can make your own with information at https://github.com/ageppert/SAO_OLED
- Furthermore… connect to whatever other I2C devices you’d like through the SAO port.

Normal Operation
The data and clock lines idle high, at 3.3V.
During bus activity, those lines rapidly pulse between 0 and 3.3V.

## 12. EEPROM for Board ID

Overview
The EEPROM stores information such as:
- Board Version and Serial Number
- Core configuration
- Custom settings

If the EEPROM is not accessible, the firmware does not know how to configure itself to use all of the available features. Substantial parts of the normal functionality of Core16 won’t work.

## 13. INFO Query

Overview
The “info” command returns valuable troubleshooting information.

Normal Operation
Establish a serial connection through the Micro USB cable.

Type “info” to display information about your particular Core16. Don’t type the quotes. Here’s an example of the output with useful details highlighted in yellow:

| | INFO | |
EEPROM S/N indicates Logic Board Type: 3 (eLBT_CORE16_PICO)
Core16 Logic Board with Raspberry Pi Pico RP2040 MCU. Hardware configuration in HardwareIOMap.h
Hardware Version: 0.1.0 | Serial Number: 300003 | Born on: 2023-10-4
Voltages: Input (Battery): 5.05, | 5V0 Rail: 5.00, 3V3 Rail: 3.29
Firmware Version: 0.8.11 | (Compiled on Apr 13 2024 at 09:35:51)
Firmware Description: All ICM (Interactive Core Memory) Kits, add option to drive Color OLED 1.5 inch from https://www.adafruit.com/product/1431
For more details see https://www.github.com/ageppert/Core64 HardwareConnectedCheckButtonHallSensors = true

From this information I see that the EEPROM can be accessed and is providing a valid serial number and hardware version. The Hall Sensors are also being detected correctly. The firmware version and 5V0/3V3 rail voltages are a function of the native firmware.

## 14. Core Matrix Wiring

Overview
Problems with some of the rows and columns could be caused by lack of continuity in corresponding wires. All four columns each have their own dedicated wire/driver. The 1st and 3rd rows share a drive circuit, as do the 2nd and 4th rows. It could also be one of the diodes or transistors in the drive circuit, especially near the top and bottom edges where they are more exposed and prone to handling damage.

Problems with all of the cores point to the elements that are common to all cores: core enable, sense, Pico W connections.

All of the Logic Board functionality is tested for each board that is shipped. Having a wide variety of customers with different levels of technical skill means that weaving the core matrix is the most likely place to introduce problems, or end up incomplete. Thus, this is the most likely place to look for problems. The following list of watch-out areas starts with the most frequent occurrences.

PICO W Soldering

It’s worth mentioning this again: Carefully inspect and verify continuity between the top of the Pico W thru-hole and the bottom of the Core16 Logic Board thru-hole. It’s easy to be fooled by just looking at the solder joint!

Row and Column continuity
Verify continuity from the top to bottom solder pads around the Core Matrix, and the left to right solder pads, on the top side of the board. Resistance should be between: 0.0 and 0.2 Ohms.

If there isn’t continuity, the solder joint needs to be gently reworked from the bottom side to break down the enamel coating of the wire. Use a slightly higher temperature than normal solder, add flux, and rub the sides of the wire enamel while gently maintaining tension on the wire with a tweezers. Maintain the tension until the solder joint solidifies to avoid creating “cold” colder joints.

Sense Wire continuity
Verify continuity of each end of the sense wire S1 to S2 solder pads, on the top side.
Resistance should be 0.0 to 0.4 Ohms.
Verify the same continuity/resistance reading across the pads of R47 (which is not populated).

Core Orientation

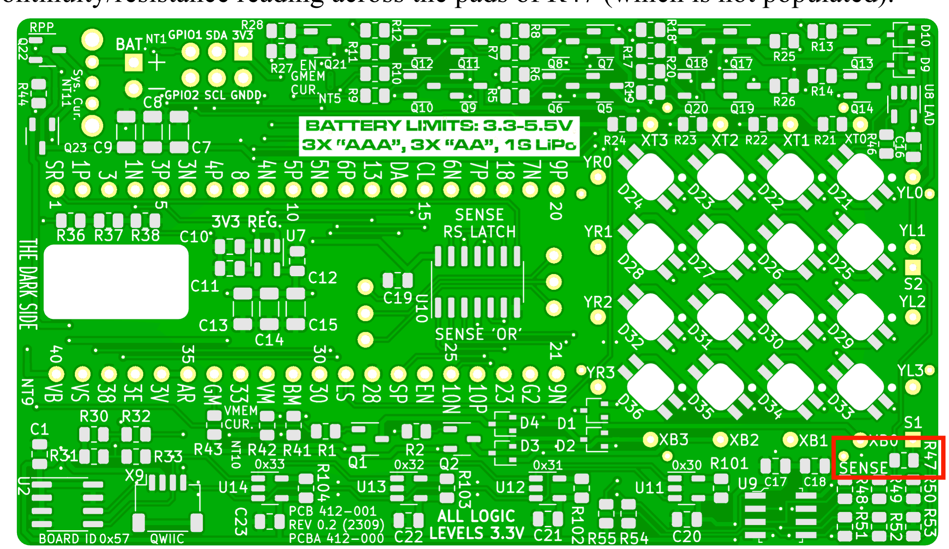
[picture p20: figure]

The cores must be installed in this alternating configuration shown by the diagonal black rectangles:

Perform the matrix wiring tests with the power disconnected from the Core16 Logic Board!

Screen Protector Wiring

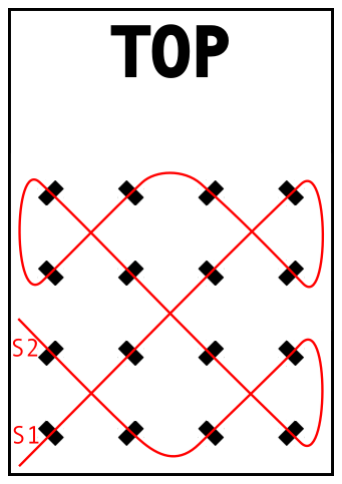
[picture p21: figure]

If you have installed the diagonal wires to hold the screen protector in place, verify they are in the correct hole positions, without any solder blobs carrying over to adjacent pads.

## 15. Core Matrix Enable

Quick Test
In mode 30… with only USB power, switch in OFF (USB) position, ground at SAO port GND, verify:
- 3.3V square 3 pulses on EN pad Pico W pin 26, bottom side of Logic Board

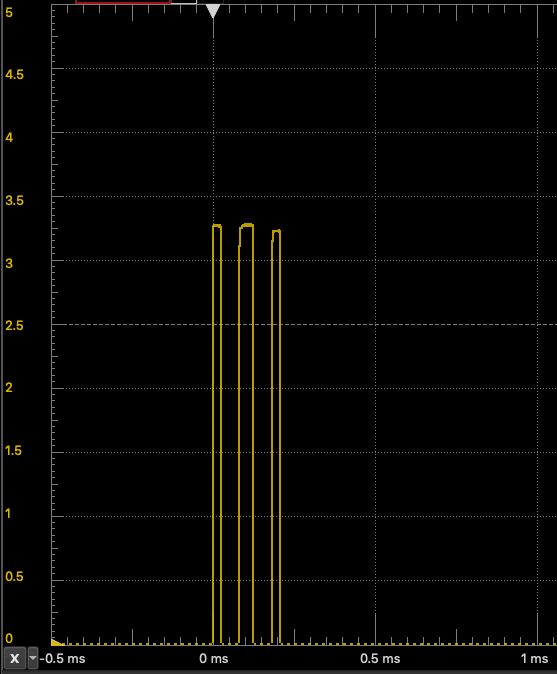
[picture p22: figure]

- Same signal at Q21 Gate (adjacent to R28)

Overview

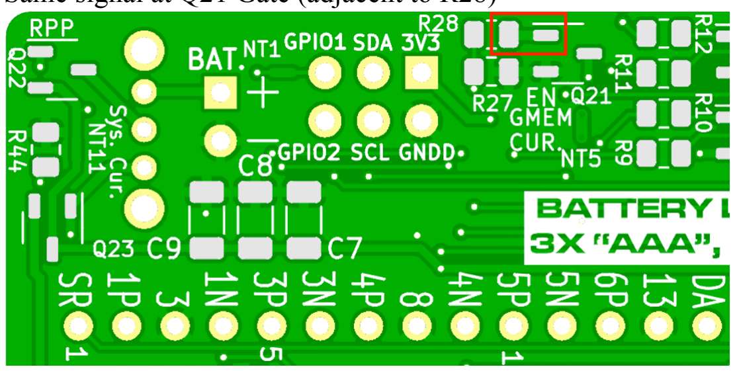
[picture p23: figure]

Core Matrix Enable connects the entire drive matrix to ground, and enables it. Failure of this section will render all cores inoperable.

## 16. Core Matrix Row and Column Drivers

Quick Test
Finish this

TO DO:

- Core Matrix Row and Column Drivers
- Core Signal Sense
- Core Signal Output Latch
- Magnetic Stylus
- RGB LEDs
- Hall Sensors
- SAO OLED (optional)
- SAO and QWIIC ports (optional accessories)

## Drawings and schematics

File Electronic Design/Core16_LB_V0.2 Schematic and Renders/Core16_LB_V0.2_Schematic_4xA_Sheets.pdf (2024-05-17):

# +V SWITCHED = 5V0

# POWER SUPPLY REVERSE

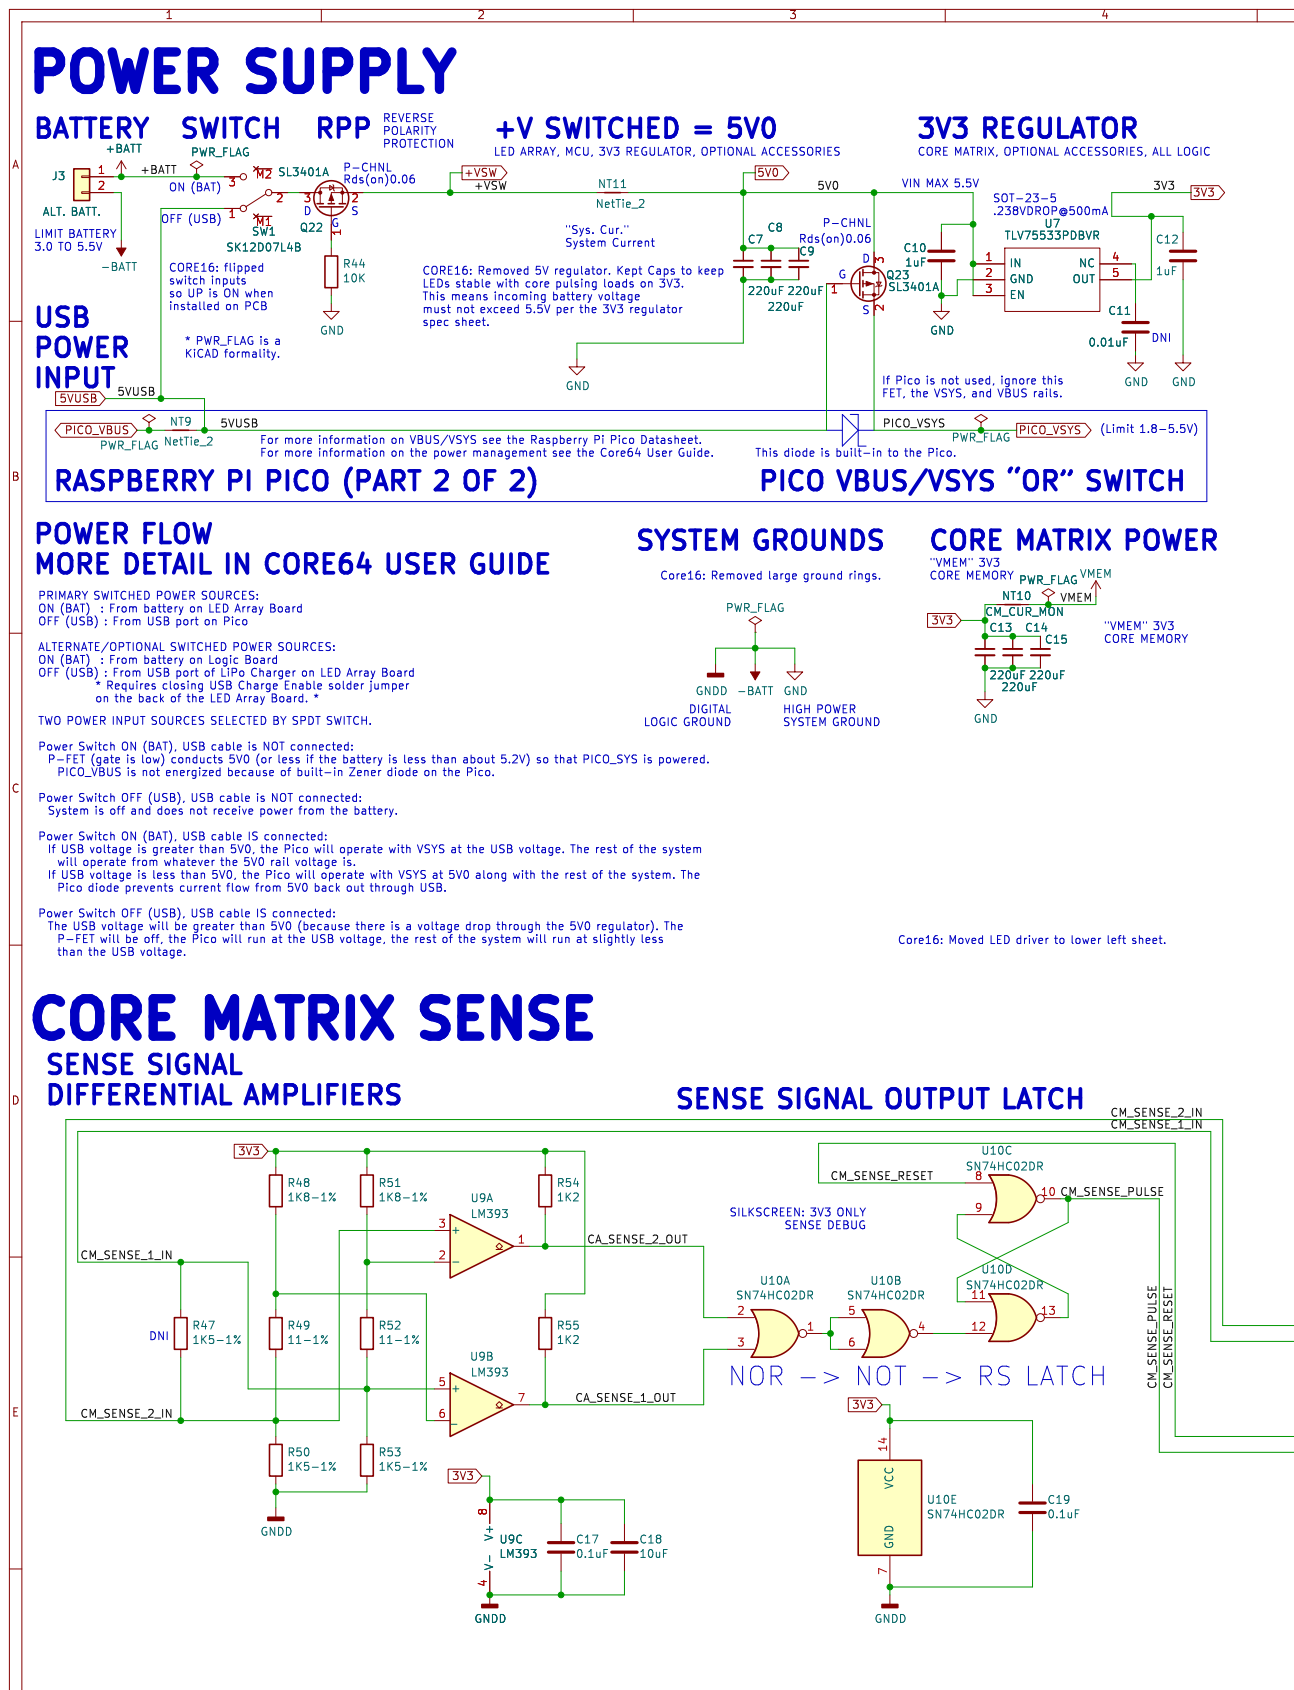
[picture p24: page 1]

LED ARRAY, MCU, 3V3 REGULATOR, OPTIONAL ACCESSORIES

CORE MATRIX, OPTIONAL ACCESSORIES, ALL LOGIC

CORE16: flipped
switch inputs
so UP is ON when

must not exceed 5.5V per the 3V3 regulator
spec sheet.

If Pico is not used, ignore this
FET, the VSYS, and VBUS rails.

PICO_VBUS
RASPBERRY PI PICO (PART 2 OF 2)

PICO VBUS/VSYS þÿ OR SWITCH

POWER FLOW
MORE DETAIL IN CORE64 USER GUIDE

Core16: Removed large ground rings.

PRIMARY SWITCHED POWER SOURCES:
OFF (USB) : From USB port on Pico

ALTERNATE/OPTIONAL SWITCHED POWER SOURCES:
OFF (USB) : From USB port of LiPo Charger on LED Array Board

on the back of the LED Array Board. *

TWO POWER INPUT SOURCES SELECTED BY SPDT SWITCH.

Power Switch ON (BAT), USB cable is NOT connected:

Power Switch OFF (USB), USB cable is NOT connected:
System is off and does not receive power from the battery.

Power Switch ON (BAT), USB cable IS connected:

Power Switch OFF (USB), USB cable IS connected:
than the USB voltage.
CORE MATRIX SENSE

Core16: Moved LED driver to lower left sheet.

SENSE SIGNAL OUTPUT LATCH

# CORE MATRIX TOP COLUMN DRIVERS

# CORE MATRIX DRIVER

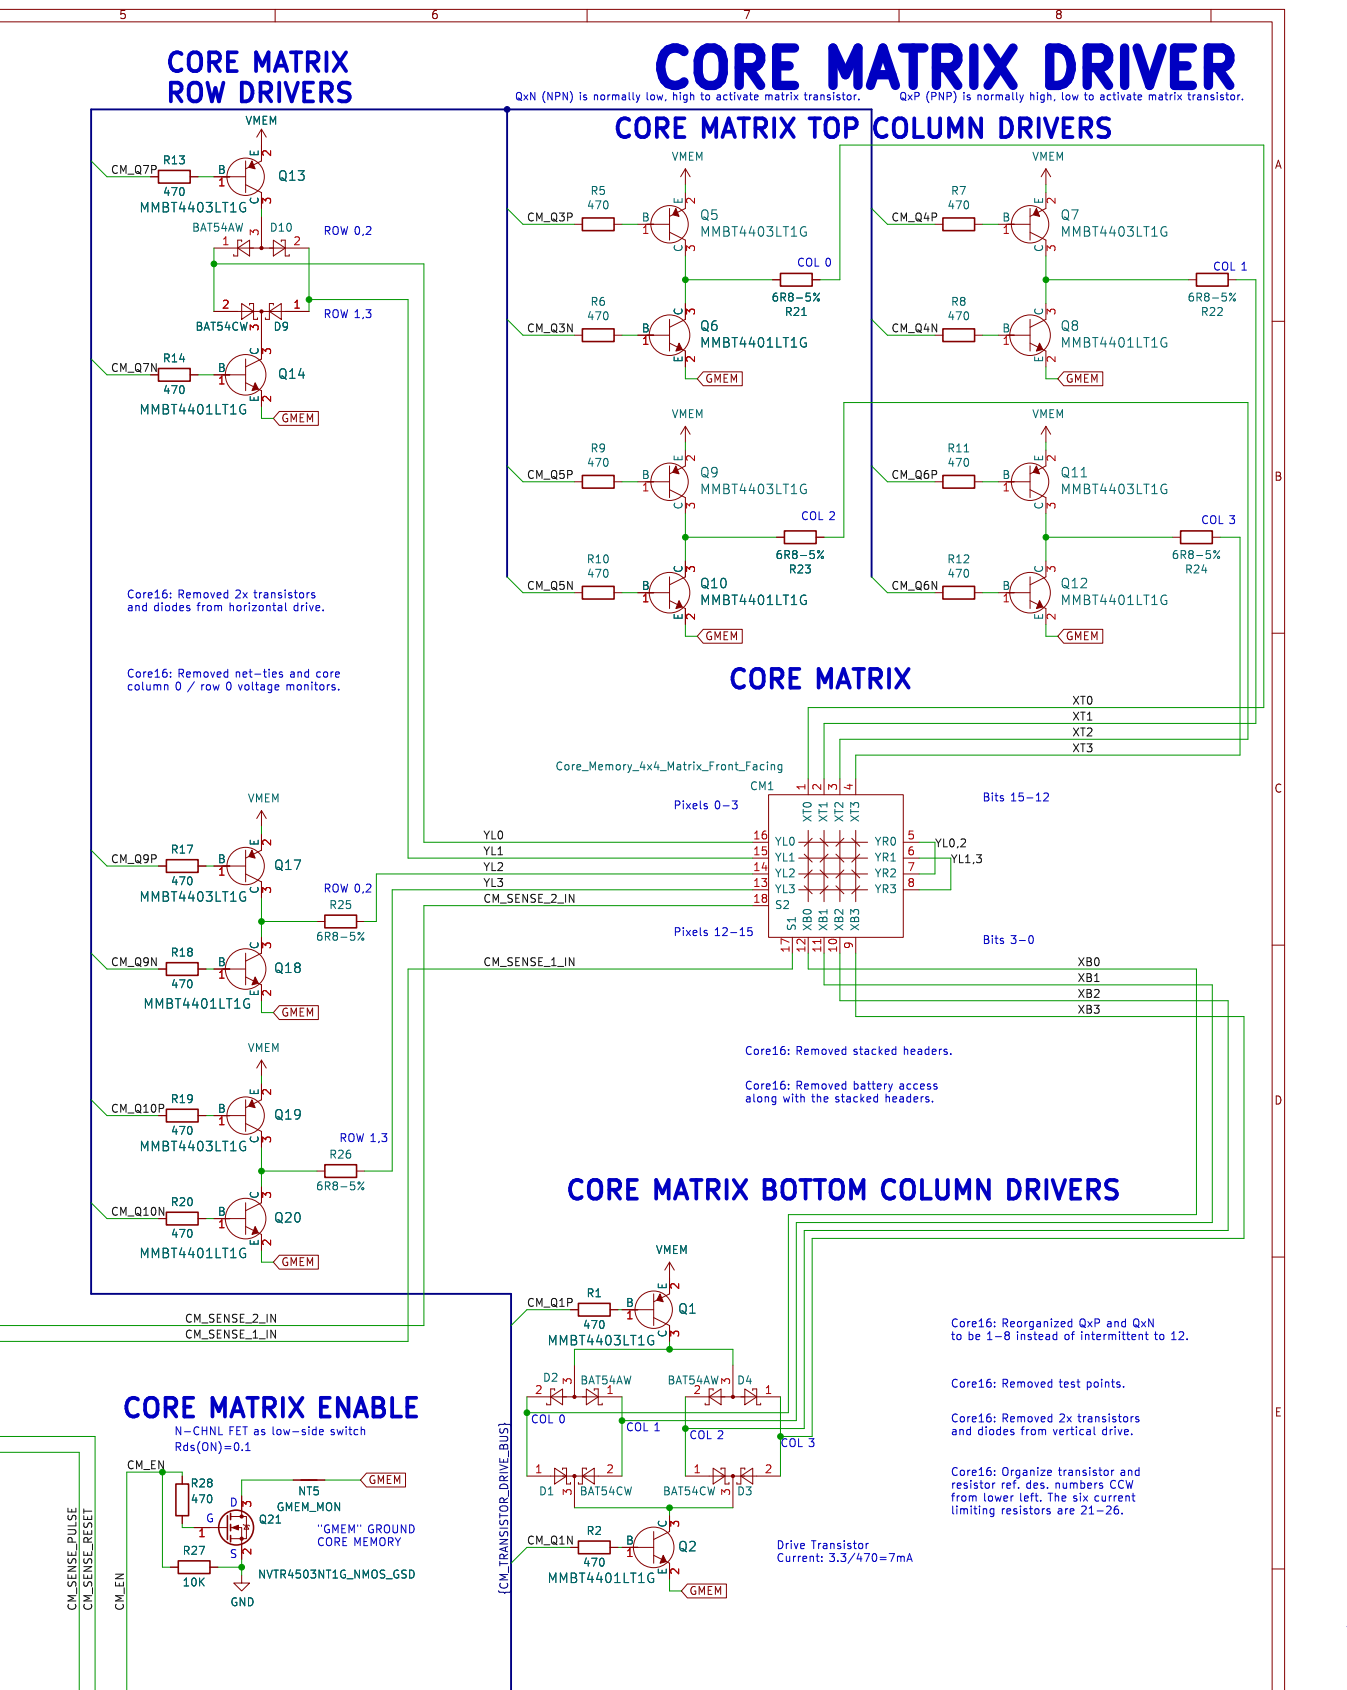
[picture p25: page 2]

CORE MATRIX BOTTOM COLUMN DRIVERS

from lower left. The six current

# RGB LED MATRIX AND HALL SENSOR BUTTONS

# HALL SENSORS

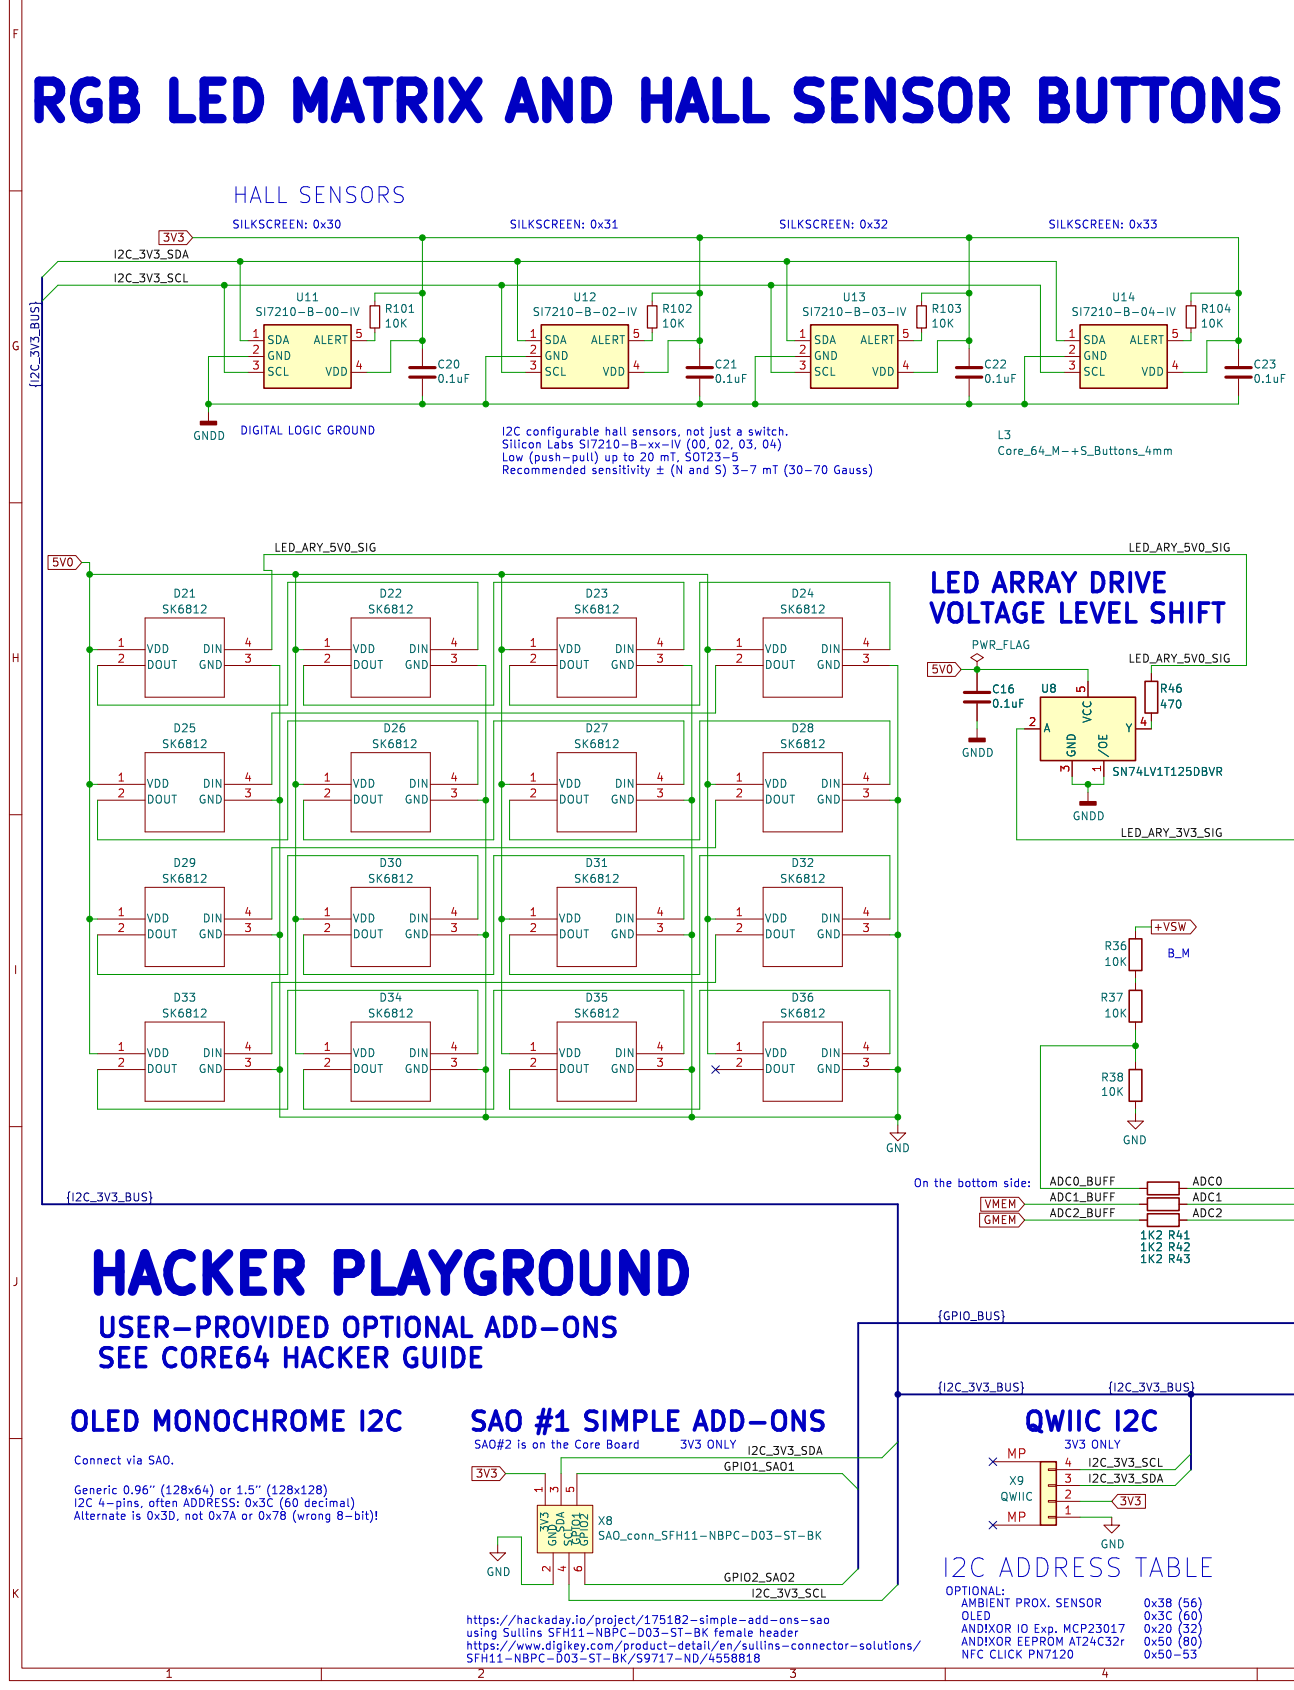
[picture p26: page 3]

SAO #1 SIMPLE ADD-ONS

OPTIONAL:
AMBIENT PROX. SENSOR
OLED
AND!XOR IO Exp. MCP23017
AND!XOR EEPROM AT24C32r
NFC CLICK PN7120

https://hackaday.io/project/175182-simple-add-ons-sao
https://www.digikey.com/product-detail/en/sullins-connector-solutions/
SFH11-NBPC-D03-ST-BK/S9717-ND/4558818

# RGB LED MATRIX AND HALL SENSOR BUTTONS

# RASPBERRY PI PICO (PART 1 OF 2)

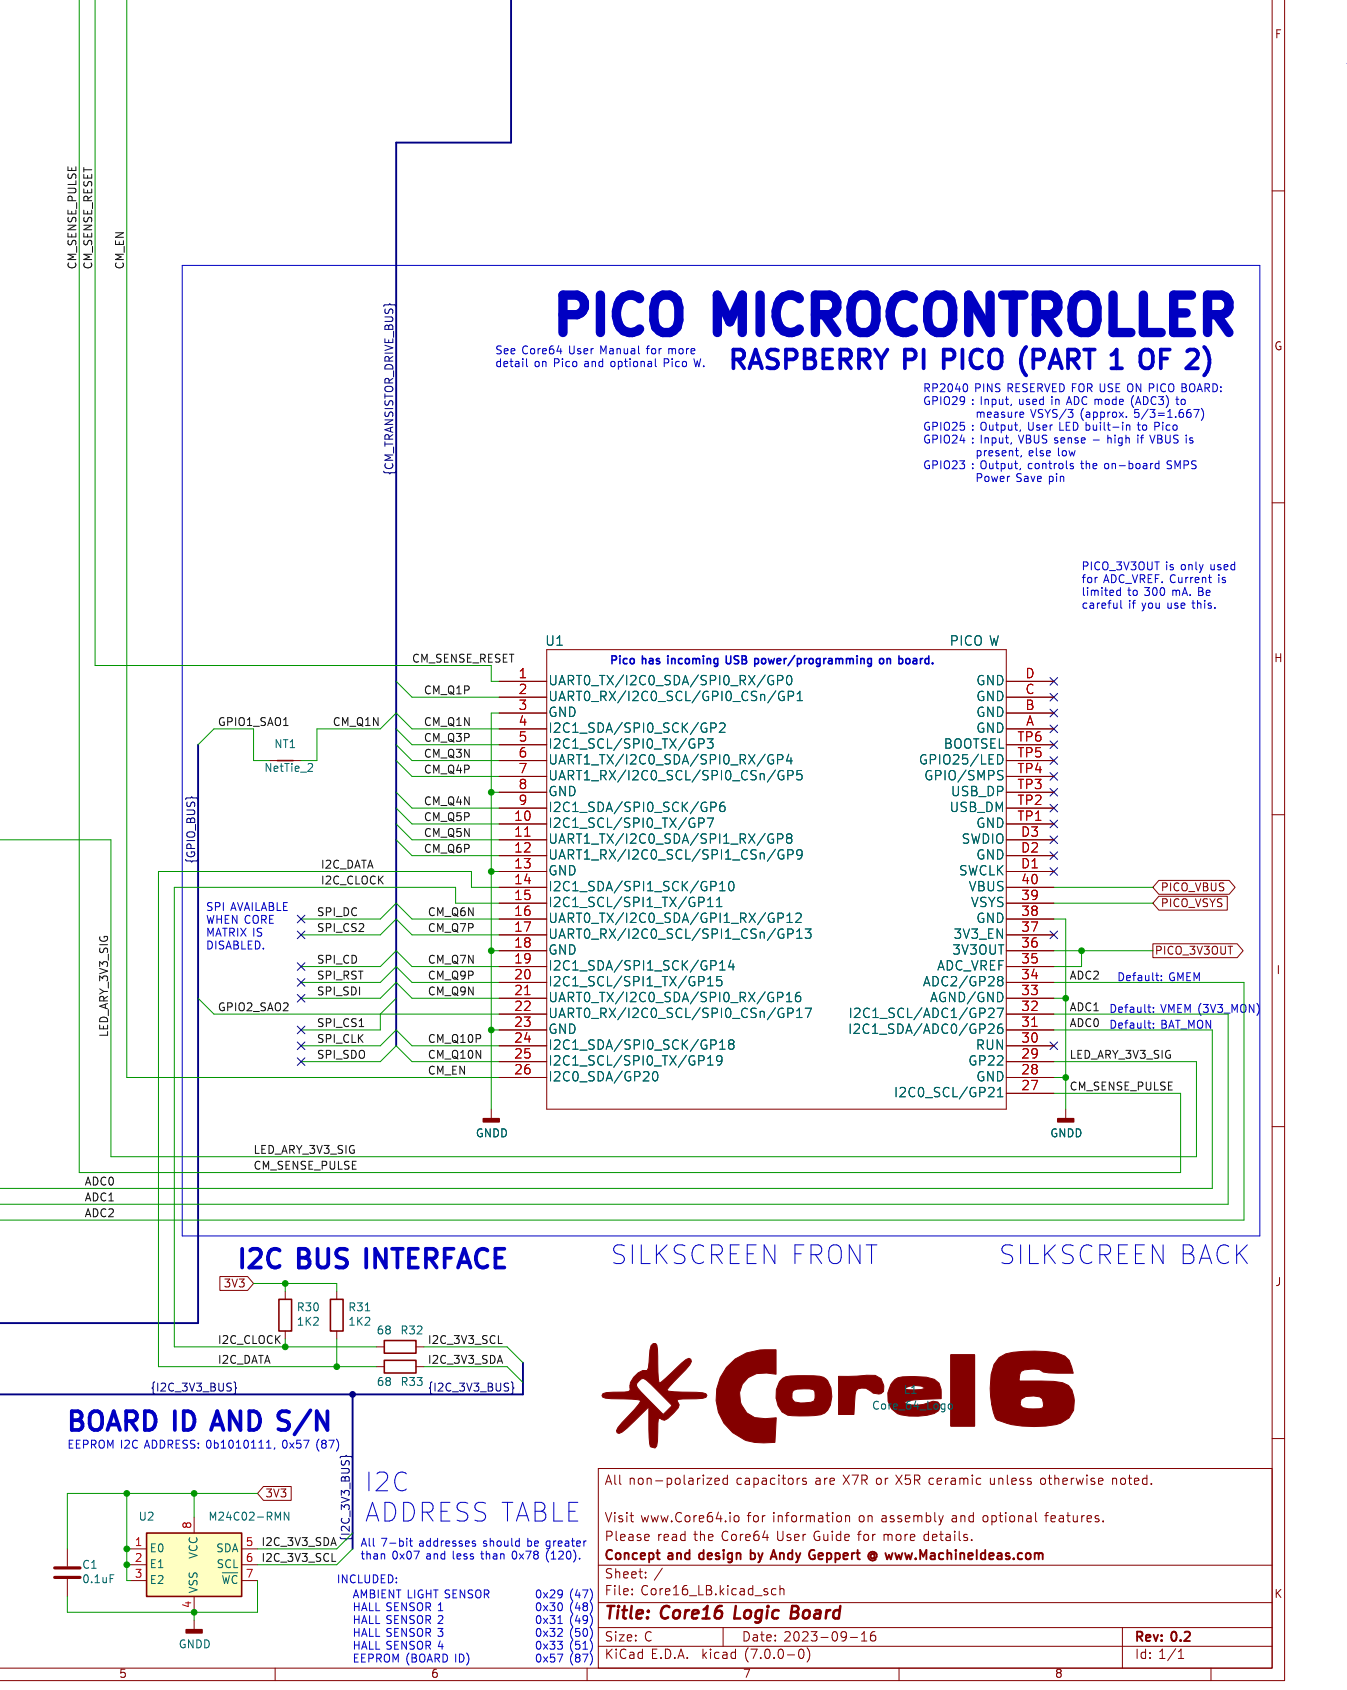
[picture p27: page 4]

See Core64 User Manual for more

RP2040 PINS RESERVED FOR USE ON PICO BOARD:
GPIO29 : Input, used in ADC mode (ADC3) to

GPIO24 : Input, VBUS sense - high if VBUS is

Concept and design by Andy Geppert @ www.MachineIdeas.com
Sheet: /
File: Core16_LB.kicad_sch
Title: Core16 Logic Board

than 0x07 and less than 0x78 (120).

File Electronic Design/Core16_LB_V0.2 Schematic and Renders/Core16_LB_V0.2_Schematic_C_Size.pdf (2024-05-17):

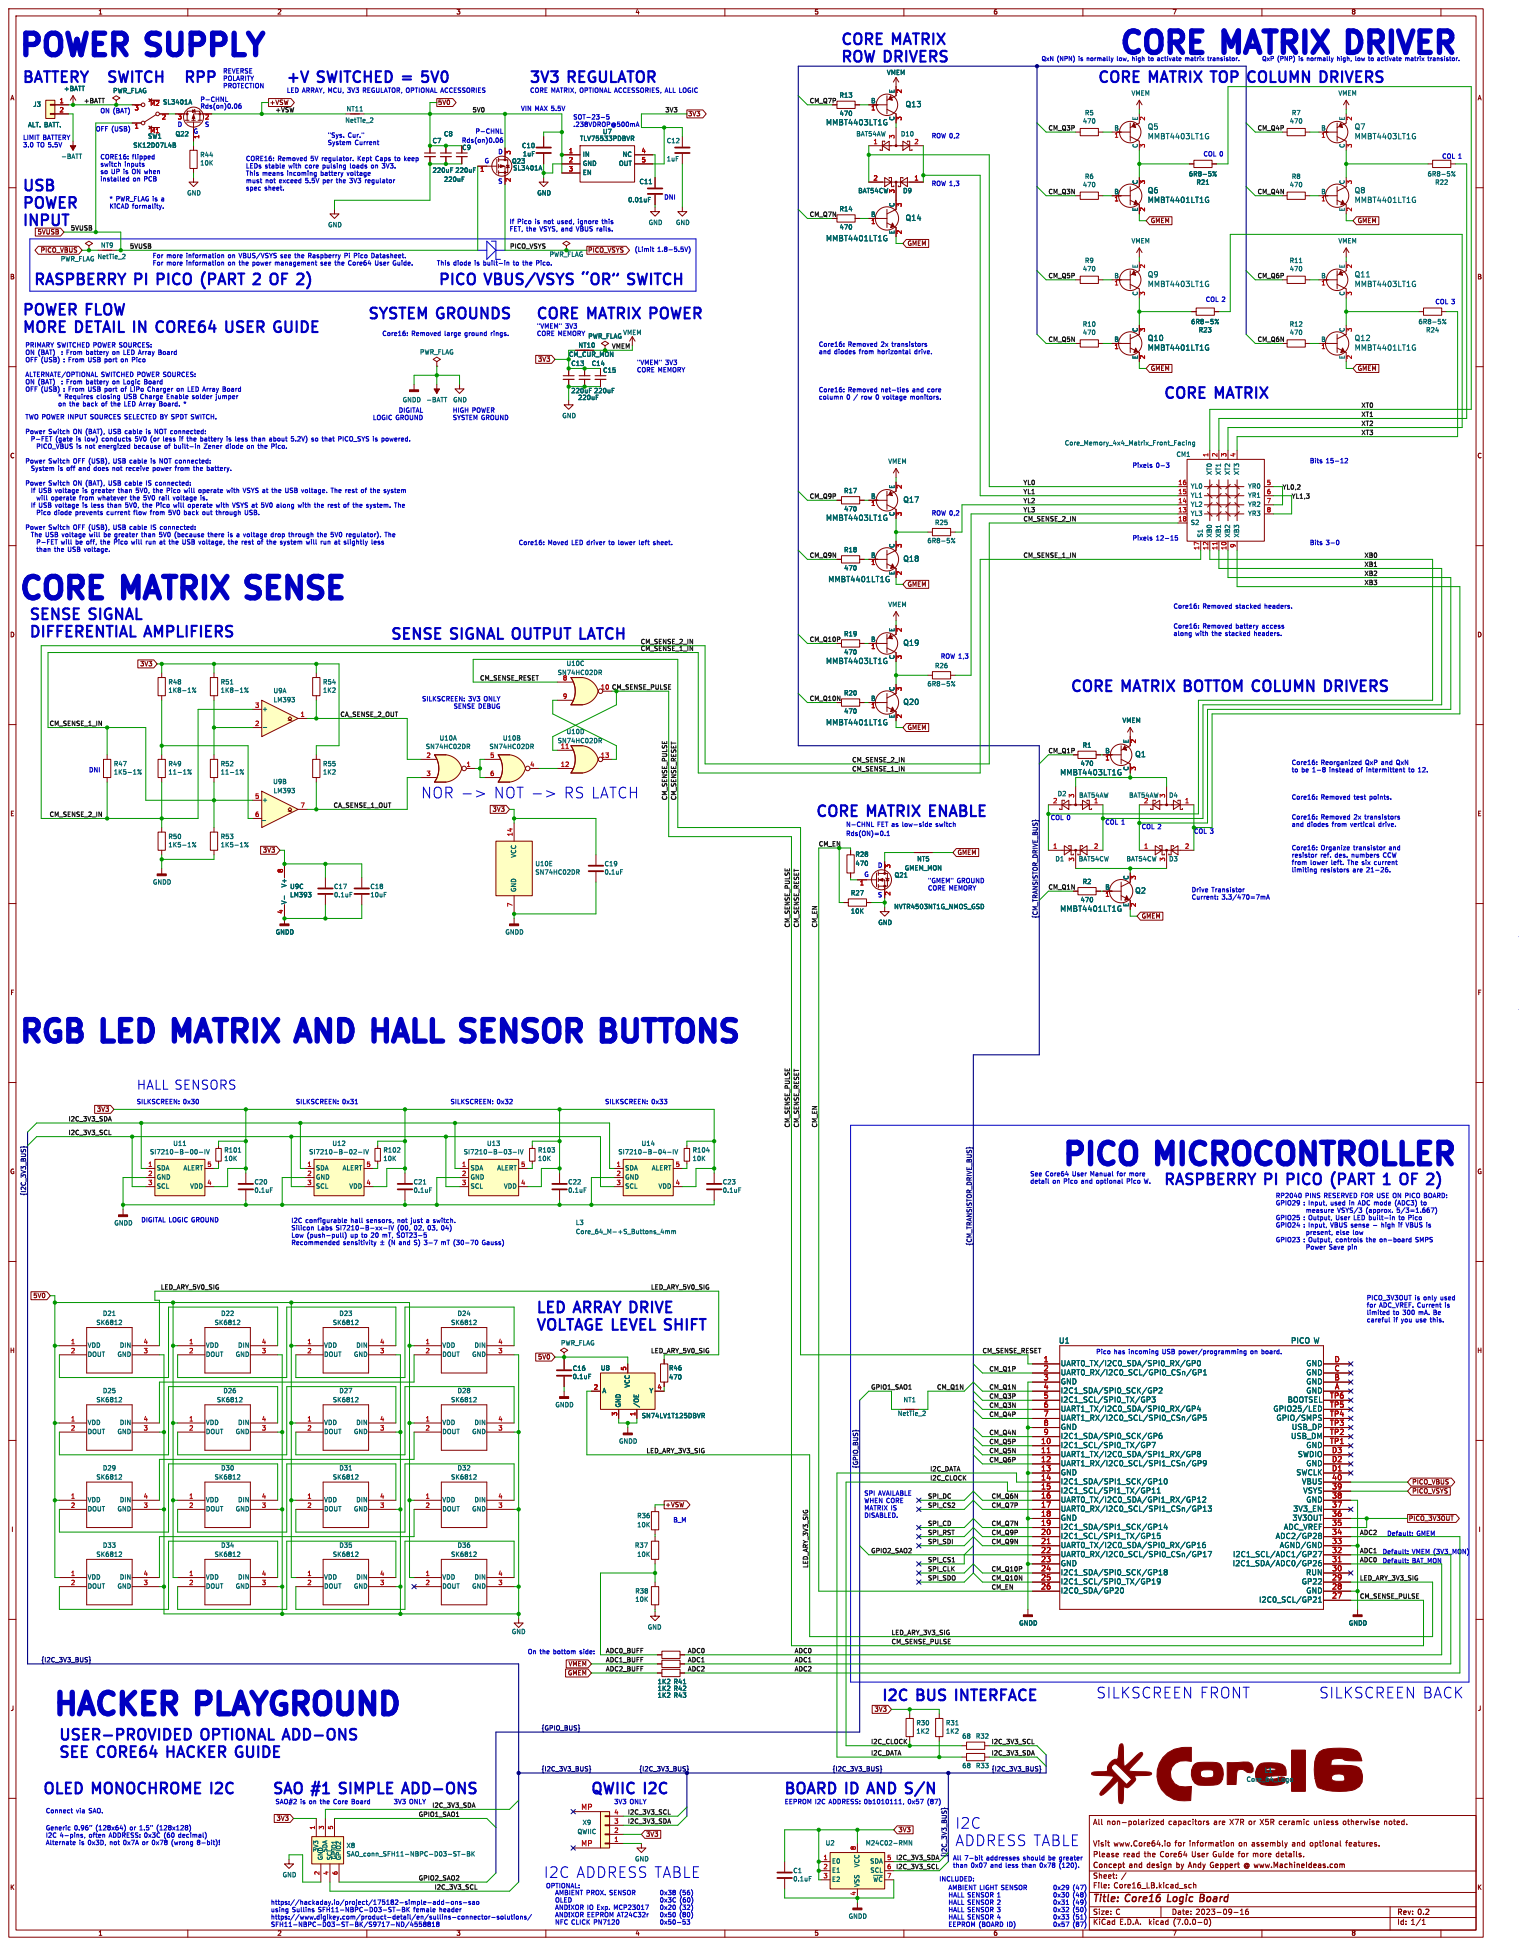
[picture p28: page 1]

CORE MATRIX
ROW DRIVERS
Rds(on)0.06 G HACKER PLAYGROUND
VIN MAX 5.5V SENSE SIGNAL

QxN (NPN) is normally low, high to activate matrix transistor.

COL 0 CORE MATRIX TOP COLUMN DRIVERS

LED ARRAY, MCU, 3V3 REGULATOR, OPTIONAL ACCESSORIES
+VSW

CORE MATRIX, OPTIONAL ACCESSORIES, ALL LOGIC

"Sys. Cur." System Current

CORE16: flipped
switch inputs
so UP is ON when

LEDs stable with core pulsing loads on 3V3. This means incoming battery voltage must not exceed 5.5V per the 3V3 regulator spec sheet.

If Pico is not used, ignore this FET, the VSYS, and VBUS rails.

* Requires closing USB Charge Enable solder jumper on the back of the LED Array Board. * RASPBERRY PI PICO (PART 2 OF 2)
POWER FLOW
MORE DETAIL IN CORE64 USER GUIDE

Core16: Removed battery access along with the stacked headers. CORE MATRIX

SYSTEM GROUNDS
column 0 / row 0 voltage monitors. CORE MATRIX ENABLE

"VMEM" 3V3 CORE MEMORY DIGITAL
Core16: Removed large ground rings.

PRIMARY SWITCHED POWER SOURCES: ON (BAT) : From battery on LED Array Board OFF (USB) : From USB port on Pico ALTERNATE/OPTIONAL SWITCHED POWER SOURCES: ON (BAT) : From battery on Logic Board OFF (USB) : From USB port of LiPo Charger on LED Array Board

If USB voltage is greater than 5V0, the Pico will operate with VSYS at the USB voltage. The rest of the system
will operate from whatever the 5V0 rail voltage is.

Core16: Moved LED driver to lower left sheet. CORE MATRIX SENSE

SENSE DEBUG SENSE SIGNAL OUTPUT LATCH

NOR -> NOT -> RS LATCH

Core16: Removed 2x transistors and diodes from vertical drive.

resistor ref. des. numbers CCW
from lower left. The six current

RGB LED MATRIX AND HALL SENSOR BUTTONS

See Core64 User Manual for more

RASPBERRY PI PICO (PART 1 OF 2)

for ADC_VREF. Current is
limited to 300 mA. Be
careful if you use this.

On the bottom side:

USER-PROVIDED OPTIONAL ADD-ONS
SEE CORE64 HACKER GUIDE

SAO #1 SIMPLE ADD-ONS

4 SDA 5 SCL 6 ~{WC}7 VCC

than 0x07 and less than 0x78 (120).
INCLUDED:
AMBIENT LIGHT SENSOR

AMBIENT PROX. SENSOR OLED

Id: 1/1 Title: Core16 Logic Board

https://hackaday.io/project/175182-simple-add-ons-sao

AND!XOR IO Exp. MCP23017 AND!XOR EEPROM AT24C32r NFC CLICK PN7120

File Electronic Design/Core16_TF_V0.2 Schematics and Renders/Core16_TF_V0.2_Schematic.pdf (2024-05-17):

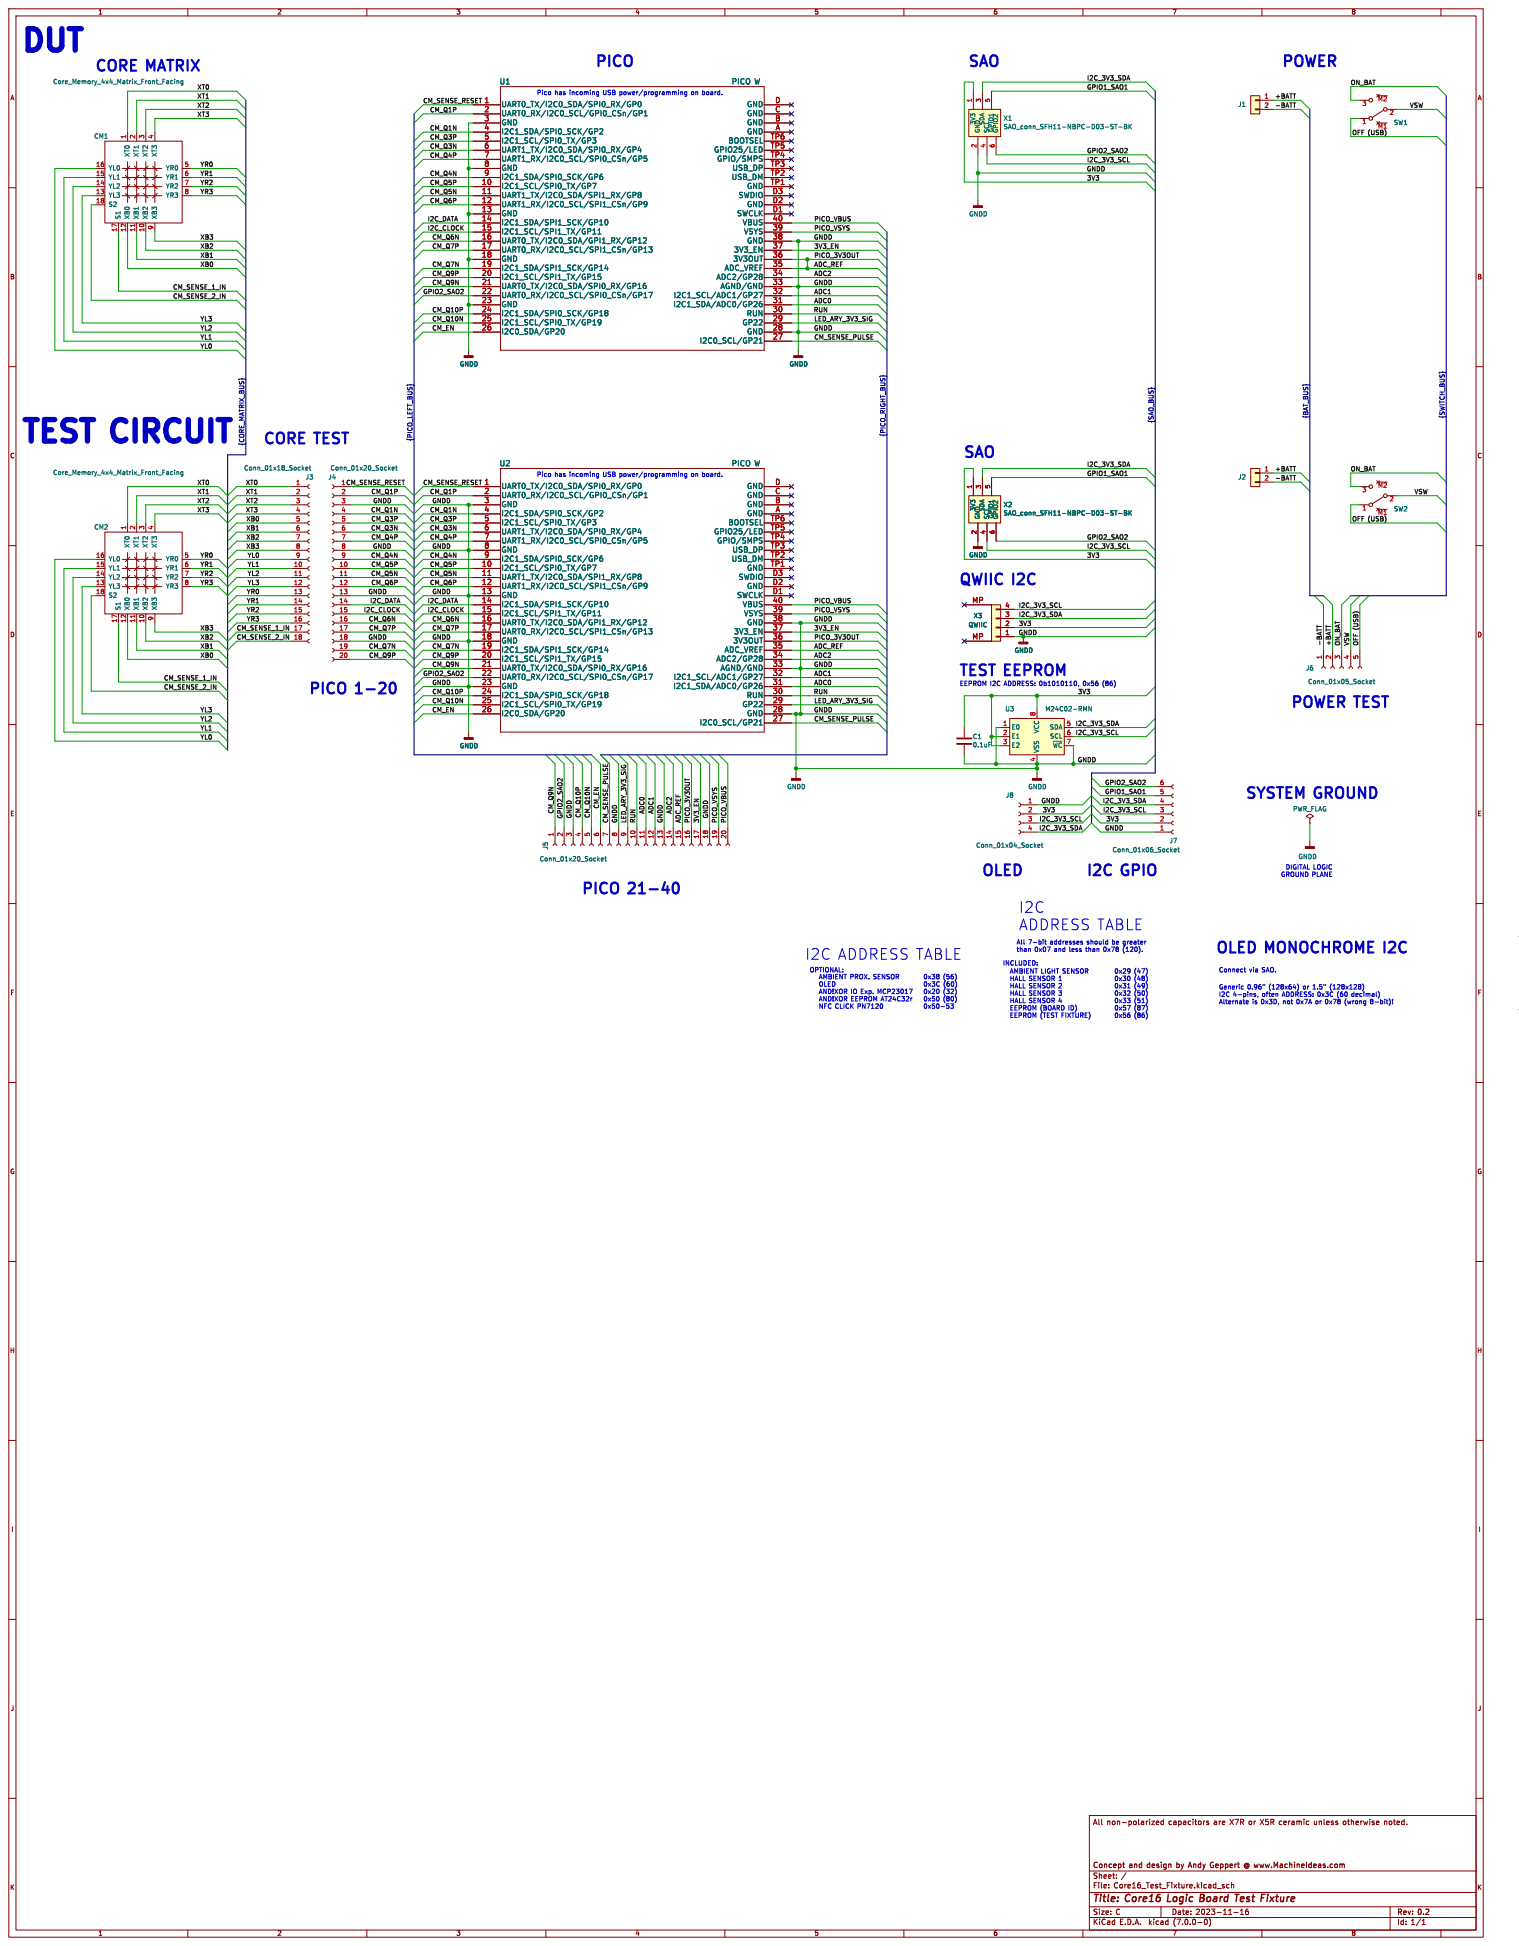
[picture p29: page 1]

6 X2SAO_conn_SFH11-NBPC-D03-ST-BK GNDD XT0

4 SDA 5 SCL 6 ~{WC}7 VCC

than 0x07 and less than 0x78 (120).
INCLUDED: AMBIENT LIGHT SENSOR

AMBIENT PROX. SENSOR OLED

AND!XOR IO Exp. MCP23017 AND!XOR EEPROM AT24C32r NFC CLICK PN7120

Id: 1/1 Title: Core16 Logic Board Test Fixture

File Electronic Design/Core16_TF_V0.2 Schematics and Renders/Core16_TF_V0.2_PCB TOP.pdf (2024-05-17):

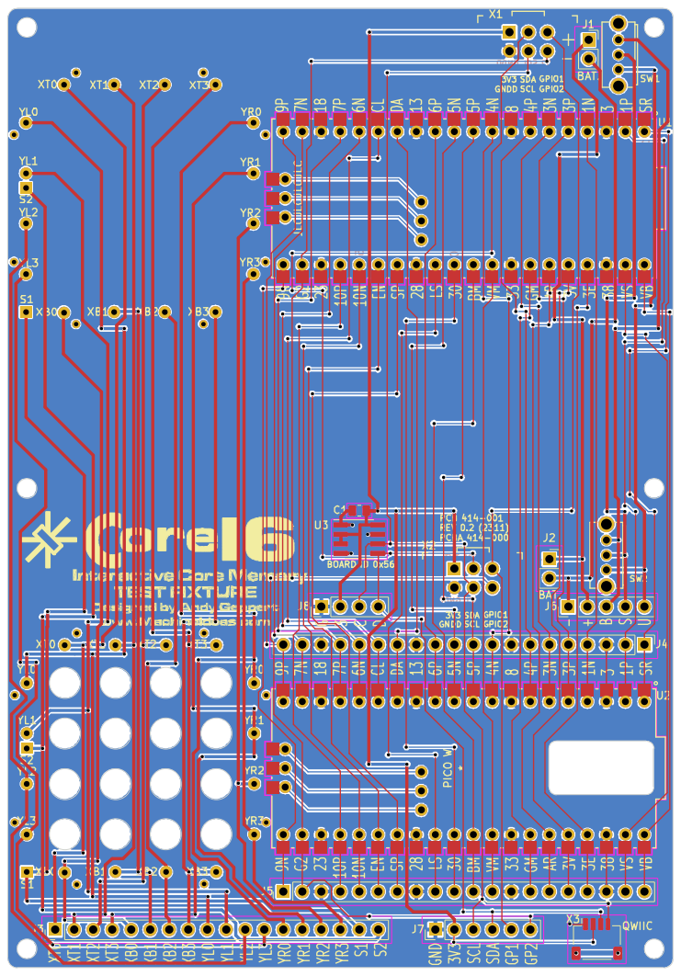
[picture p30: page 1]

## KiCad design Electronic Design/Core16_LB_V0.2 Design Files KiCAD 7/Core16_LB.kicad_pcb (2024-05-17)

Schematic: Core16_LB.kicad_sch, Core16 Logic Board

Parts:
C1, C16, C17, C19: 0.1uF; C_0805_2012Metric; LCSC C28233
C7, C8, C9, C13, C14, C15: 220uF; C_1206_3216Metric; LCSC C412252
C10, C12: 1uF; C_0805_2012Metric; LCSC C28323
C11: 0.01uF; C_0805_2012Metric; LCSC C1710
C18: 10uF; C_0805_2012Metric; LCSC C17024
C20, C21, C22, C23: 0.1uF; C_0805_2012Metric; LCSC C396718
CM1: Core_Memory_4x4_Matrix_Front_Facing; core_16_6.75mm_square_front_facing
D1, D3, D9: BAT54CW; SOT-323_SC-70; MPN BAT54CW-7-F; LCSC C83573
D2, D4, D10: BAT54AW; SOT-323_SC-70; MPN BAT54AW-7-F; LCSC C78261
D21, D22, D23, D24, D25, D26, D27, D28, D29, D30, D31, D32, D33, D34, D35, D36: SK6812; 4960_ADA_REV_RGB_LED_short_pads; MPN SK6812-E; Digi-Key_PN 1528-4960-ND
J3: ALT. BATT.; PinSocket_1x02_P2.54mm_Vertical
L1: Core_64_Logo; Core16_w_core_symbol
L3: Core_64_M-+S_Buttons_4mm; Core64-M_-_+_S_Buttons
NT1, NT9, NT11: NetTie_2; NetTie-2_SMD_Pad0.5mm
NT5: GMEM_MON; NetTie-2_THT_Pad0.3mm
NT10: CM_CUR_MON; NetTie-2_SMD_Pad0.5mm
Q1, Q5, Q7, Q9, Q11, Q13, Q17, Q19: MMBT4403LT1G; SOT-23-3; MPN MMBT4403LT1G; Digi-Key_PN MMBT4403LT1GOSCT-ND
Q2, Q6, Q8, Q10, Q12, Q14, Q18, Q20: MMBT4401LT1G; SOT-23-3; MPN MMBT4401LT1G; Digi-Key_PN MMBT4401LT1GOSCT-ND
Q21: NVTR4503NT1G_NMOS_GSD; SOT-23-3; MPN NVTR4503NT1G; LCSC C20917
Q22, Q23: SL3401A; SOT-23-3; MPN SL3401A-TP; LCSC C350311
R1, R2, R5, R6, R7, R8, R9, R10, R11, R12, R13, R14, R17, R18, R19, R20, R28, R46: 470; R_0805_2012Metric; LCSC C17710
R21, R22, R23, R24, R25, R26: 6R8-5%; R_0805_2012Metric; LCSC C17774
R27, R36, R37, R38, R44, R101, R102, R103, R104: 10K; R_0805_2012Metric; LCSC C269724
R30, R31, R41, R42, R43, R54, R55: 1K2; R_0805_2012Metric; LCSC C17379
R32, R33: 68; R_0805_2012Metric; LCSC C17802
R47, R50, R53: 1K5-1%; R_0805_2012Metric; LCSC C4310
R48, R51: 1K8-1%; R_0805_2012Metric; LCSC C17398
R49, R52: 11-1%; R_0805_2012Metric; LCSC C17430
SW1: SK12D07L4B; SK12D07VG4; MPN OS102011MA1QN1; LCSC C480340
U1: PICO W; Pico_SC0915_THRUHOLE_CUTOUTS
U2: M24C02-RMN; SOIC-8_3.9x4.9mm_P1.27mm; MPN M24C02-WMN6TP; LCSC C7562
U7: TLV75533PDBVR; SOT-23-5; MPN ME6211C33M5G-N; LCSC C82942
U8: SN74LV1T125DBVR; SOT-23-5; MPN SN74LV1T125DBVR; LCSC C473338
U9: LM393; SOIC-8_W3.9mm; MPN LM393DT; LCSC C7955
U10: SN74HC02DR; SOIC-14_3.9x8.7mm_P1.27mm; MPN SN74HC02DR; LCSC C350559
U11: SI7210-B-00-IV; SOT-23-5; MPN SI7210-B-00-IV; Digi-Key_PN 336-4068-ND
U12: SI7210-B-02-IV; SOT-23-5; MPN SI7210-B-02-IV; Digi-Key_PN 336-SI7210-B-02-IV-ND
U13: SI7210-B-03-IV; SOT-23-5; MPN SI7210-B-03-IV; Digi-Key_PN 336-SI7210-B-03-IV-ND
U14: SI7210-B-04-IV; SOT-23-5; MPN SI7210-B-04-IV; Digi-Key_PN 336-4056-ND
X8: SAO_conn_SFH11-NBPC-D03-ST-BK; Badgelife-SAOv169-BADGE-2x3; MPN SFH11-NBPC-D03-ST-BK
X9: QWIIC; JST_SH_SM04B-SRSS-TB_1x04-1MP_P1.00mm_Horizontal; MPN SM04B-SRSS-TB; LCSC C160404

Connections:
3V3: C1.1, C12.1, C13.1, C14.1, C15.1, C17.1, C18.1, C19.1, C20.1, C21.1, C22.1, C23.1, NT10.1, R30.1, R31.1, R48.1, R51.1, R54.1, R55.1, R101.1, R102.1, R103.1, R104.1, U2.1 (E0), U2.2 (E1), U2.3 (E2), U2.8 (VCC), U7.5 (OUT), U9.8 (V+), U10.14 (VCC), U11.4 (VDD), U12.4 (VDD), U13.4 (VDD), U14.4 (VDD), X8.1 (3V3), X9.2
5V0: C7.1, C8.1, C9.1, C10.1, C16.1, D21.1 (VDD), D22.1 (VDD), D23.1 (VDD), D24.1 (VDD), D25.1 (VDD), D26.1 (VDD), D27.1 (VDD), D28.1 (VDD), D29.1 (VDD), D30.1 (VDD), D31.1 (VDD), D32.1 (VDD), D33.1 (VDD), D34.1 (VDD), D35.1 (VDD), D36.1 (VDD), NT11.2, Q23.3 (D), U7.1 (IN), U7.3 (EN), U8.5 (VCC)
5VUSB: NT9.2, Q23.1 (G), SW1.1 (A)
+BATT: J3.1, SW1.3 (C)
+VSW: NT11.1, Q22.2 (S), R36.2
-BATT: C1.2, C7.2, C8.2, C9.2, C10.2, C11.2, C12.2, C13.2, C14.2, C15.2, C16.2, C17.2, C18.2, C19.2, C20.2, C21.2, C22.2, C23.2, D21.3 (GND), D22.3 (GND), D23.3 (GND), D24.3 (GND), D25.3 (GND), D26.3 (GND), D27.3 (GND), D28.3 (GND), D29.3 (GND), D30.3 (GND), D31.3 (GND), D32.3 (GND), D33.3 (GND), D34.3 (GND), D35.3 (GND), D36.3 (GND), J3.2, Q21.2 (S), R27.1, R38.2, R44.2, R50.2, R53.2, U1.3 (GND), U1.8 (GND), U1.13 (GND), U1.18 (GND), U1.23 (GND), U1.28 (GND), U1.33 (AGND/GND), U1.38 (GND), U2.4 (VSS), U2.7 (~WC), U7.2 (GND), U8.1 (/OE), U8.3 (GND), U9.4 (V-), U10.7 (GND), U11.2 (GND), U12.2 (GND), U13.2 (GND), U14.2 (GND), X8.2 (GND), X9.1
/ADC0: R41.1, U1.31 (I2C1_SDA/ADC0/GP26)
/ADC0_BUFF: R37.1, R38.1, R41.2
/ADC1: R42.1, U1.32 (I2C1_SCL/ADC1/GP27)
/ADC2: R43.1, U1.34 (ADC2/GP28)
/CA_SENSE_1_OUT: R55.2, U9.7, U10.3
/CA_SENSE_2_OUT: R54.2, U9.1, U10.2
/CM_EN: R27.2, R28.1, U1.26 (I2C0_SDA/GP20)
/CM_Q1N: NT1.2, R2.2, U1.4 (I2C1_SDA/SPI0_SCK/GP2)
/CM_Q1P: R1.2, U1.2 (UART0_RX/I2C0_SCL/GPI0_CSn/GP1)
/CM_Q3N: R6.2, U1.6 (UART1_TX/I2C0_SDA/SPI0_RX/GP4)
/CM_Q3P: R5.2, U1.5 (I2C1_SCL/SPI0_TX/GP3)
/CM_Q4N: R8.2, U1.9 (I2C1_SDA/SPI0_SCK/GP6)
/CM_Q4P: R7.2, U1.7 (UART1_RX/I2C0_SCL/SPI0_CSn/GP5)
/CM_Q5N: R10.2, U1.11 (UART1_TX/I2C0_SDA/SPI1_RX/GP8)
/CM_Q5P: R9.2, U1.10 (I2C1_SCL/SPI0_TX/GP7)
/CM_Q6N: R12.2, U1.16 (UART0_TX/I2C0_SDA/GPI1_RX/GP12)
/CM_Q6P: R11.2, U1.12 (UART1_RX/I2C0_SCL/SPI1_CSn/GP9)
/CM_Q7N: R14.2, U1.19 (I2C1_SDA/SPI1_SCK/GP14)
/CM_Q7P: R13.2, U1.17 (UART0_RX/I2C0_SCL/SPI1_CSn/GP13)
/CM_Q9N: R18.2, U1.21 (UART0_TX/I2C0_SDA/SPI0_RX/GP16)
/CM_Q9P: R17.2, U1.20 (I2C1_SCL/SPI1_TX/GP15)
/CM_Q10N: R20.2, U1.25 (I2C1_SCL/SPI0_TX/GP19)
/CM_Q10P: R19.2, U1.24 (I2C1_SDA/SPI0_SCK/GP18)
/CM_SENSE_1_IN: CM1.17 (S1), R47.1, R52.2, R53.1, U9.5 (+)
/CM_SENSE_2_IN: CM1.18 (S2), R47.2, R49.2, R50.1, U9.3 (+)
/CM_SENSE_PULSE: U1.27 (I2C0_SCL/GP21), U10.10, U10.11
/CM_SENSE_RESET: U1.1 (UART0_TX/I2C0_SDA/SPI0_RX/GP0), U10.8
/GPIO1_SAO1: NT1.1, X8.5 (GPIO1)
/GPIO2_SAO2: U1.22 (UART0_RX/I2C0_SCL/SPI0_CSn/GP17), X8.6 (GPIO2)
/I2C_3V3_SCL: R32.2, U2.6 (SCL), U11.3 (SCL), U12.3 (SCL), U13.3 (SCL), U14.3 (SCL), X8.4 (SCL), X9.4
/I2C_3V3_SDA: R33.1, U2.5 (SDA), U11.1 (SDA), U12.1 (SDA), U13.1 (SDA), U14.1 (SDA), X8.3 (SDA), X9.3
/I2C_CLOCK: R30.2, R32.1, U1.15 (I2C1_SCL/SPI1_TX/GP11)
/I2C_DATA: R31.2, R33.2, U1.14 (I2C1_SDA/SPI1_SCK/GP10)
/LED_ARY_3V3_SIG: U1.29 (GP22), U8.2 (A)
/LED_ARY_5V0_SIG: D21.4 (DIN), R46.1
/XB0: CM1.12 (XB0), D1.1, D2.2
/XB1: CM1.11 (XB1), D1.2, D2.1
/XB2: CM1.10 (XB2), D3.1, D4.2
/XB3: CM1.9 (XB3), D3.2, D4.1
/XT0: CM1.1 (XT0), R21.2
/XT1: CM1.2 (XT1), R22.1
/XT2: CM1.3 (XT2), R23.1
/XT3: CM1.4 (XT3), R24.1
/YL0: CM1.16 (YL0), D9.2, D10.1
/YL0,2: CM1.5 (YR0), CM1.7 (YR2)
/YL1: CM1.15 (YL1), D9.1, D10.2
/YL1,3: CM1.6 (YR1), CM1.8 (YR3)
/YL2: CM1.14 (YL2), R25.1
/YL3: CM1.13 (YL3), R26.1
GMEM: NT5.2, Q2.2 (E), Q6.2 (E), Q8.2 (E), Q10.2 (E), Q12.2 (E), Q14.2 (E), Q18.2 (E), Q20.2 (E), R43.2
unnamed: D21.2 (DOUT), D22.4 (DIN)
unnamed: D22.2 (DOUT), D23.4 (DIN)
unnamed: D23.2 (DOUT), D24.4 (DIN)
unnamed: D24.2 (DOUT), D25.4 (DIN)
unnamed: D25.2 (DOUT), D26.4 (DIN)
unnamed: D26.2 (DOUT), D27.4 (DIN)
unnamed: D27.2 (DOUT), D28.4 (DIN)
unnamed: D28.2 (DOUT), D29.4 (DIN)
unnamed: D29.2 (DOUT), D30.4 (DIN)
unnamed: D30.2 (DOUT), D31.4 (DIN)
unnamed: D31.2 (DOUT), D32.4 (DIN)
unnamed: D32.2 (DOUT), D33.4 (DIN)
unnamed: D33.2 (DOUT), D34.4 (DIN)
unnamed: D34.2 (DOUT), D35.4 (DIN)
unnamed: D35.2 (DOUT), D36.4 (DIN)
unnamed: Q1.1 (B), R1.1
unnamed: D2.3, D4.3, Q1.3 (C)
unnamed: Q2.1 (B), R2.1
unnamed: D1.3, D3.3, Q2.3 (C)
unnamed: Q5.1 (B), R5.1
unnamed: Q5.3 (C), Q6.3 (C), R21.1
unnamed: Q6.1 (B), R6.1
unnamed: Q7.1 (B), R7.1
unnamed: Q7.3 (C), Q8.3 (C), R22.2
unnamed: Q8.1 (B), R8.1
unnamed: Q9.1 (B), R9.1
unnamed: Q10.1 (B), R10.1
unnamed: Q9.3 (C), Q10.3 (C), R23.2
unnamed: Q11.1 (B), R11.1
unnamed: Q11.3 (C), Q12.3 (C), R24.2
unnamed: Q12.1 (B), R12.1
unnamed: Q13.1 (B), R13.1
unnamed: D10.3, Q13.3 (C)
unnamed: Q14.1 (B), R14.1
unnamed: D9.3, Q14.3 (C)
unnamed: Q17.1 (B), R17.1
unnamed: Q17.3 (C), Q18.3 (C), R25.2
unnamed: Q18.1 (B), R18.1
unnamed: Q19.1 (B), R19.1
unnamed: Q19.3 (C), Q20.3 (C), R26.2
unnamed: Q20.1 (B), R20.1
unnamed: NT5.1, Q21.3 (D)
unnamed: Q21.1 (G), R28.2
unnamed: Q22.3 (D), SW1.2 (B)
unnamed: Q22.1 (G), R44.1
unnamed: R36.1, R37.2
unnamed: C11.1, U7.4 (NC)
unnamed: R46.2, U8.4 (Y)
unnamed: R51.2, R52.1, U9.2 (-)
unnamed: R48.2, R49.1, U9.6 (_)
unnamed: U10.1, U10.5, U10.6
unnamed: U10.4, U10.12
unnamed: U10.9, U10.13
unnamed: R101.2, U11.5 (ALERT)
unnamed: R102.2, U12.5 (ALERT)
unnamed: R103.2, U13.5 (ALERT)
unnamed: R104.2, U14.5 (ALERT)
PICO_3V3OUT: U1.35 (ADC_VREF), U1.36 (3V3OUT)
PICO_VBUS: NT9.1, U1.40 (VBUS)
PICO_VSYS: Q23.2 (S), U1.39 (VSYS)
VMEM: NT10.2, Q1.2 (E), Q5.2 (E), Q7.2 (E), Q9.2 (E), Q11.2 (E), Q13.2 (E), Q17.2 (E), Q19.2 (E), R42.2

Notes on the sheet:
Bits 3-0
SILKSCREEN FRONT
INCLUDED:
QxP (PNP) is normally high, low to activate matrix transistor.
AMBIENT PROX. SENSOR OLED AND!XOR IO Exp. MCP23017 AND!XOR EEPROM AT24C32r NFC CLICK PN7120
P-CHNL
C7-9,10-15 D - H - J3 JP - NT9,10,11 Q22-23 R44 SW1 TP - U7 X -
HACKER PLAYGROUND
https://hackaday.io/project/175182-simple-add-ons-sao using Sullins SFH11-NBPC-D03-ST-BK female header https://www.digikey.com/product-detail/en/sullins-connector-solutions/ SFH11-NBPC-D03-ST-BK/S9717-ND/4558818
DIGITAL LOGIC GROUND
SAO #1 SIMPLE ADD-ONS
Bits 15-12
Core16: Removed battery access along with the stacked headers.
I2C ADDRESS TABLE
This diode is built-in to the Pico.
C16 D21-36 H - J - JP - NT - Q - R36-30, 41-43, 46, 101-104 SW - TP - U8,11-14 X8-9
POWER FLOW MORE DETAIL IN CORE64 USER GUIDE
Rds(ON)=0.1
Pico has incoming USB power/programming on board.
COL 0
B_M
DNI
PICO MICROCONTROLLER
C - D1-4, 9-10 H - J - JP - NT5 Q1-20, 21 R1-20, 21-26, 27-28 SW - TP - U - X -
HALL SENSORS
Core16: Removed net-ties and core column 0 / row 0 voltage monitors.
L1-???
SENSE SIGNAL OUTPUT LATCH
NOR -> NOT -> RS LATCH
CORE MATRIX ROW DRIVERS
Pixels 0-3
TWO POWER INPUT SOURCES SELECTED BY SPDT SWITCH. Power Switch ON (BAT), USB cable is NOT connected: P-FET (gate is low) conducts 5V0 (or less if the battery is less than about 5.2V) so that PICO_SYS is powered. PICO_VBUS is not energized because of built-in Zener diode on the Pico. Power Switch OFF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
Default: VMEM (3V3_MON)
CORE MATRIX BOTTOM COLUMN DRIVERS
CORE16: flipped switch inputs so UP is ON when installed on PCB
SOT-23-5 .238VDROP@500mA
Core16: Moved LED driver to lower left sheet.
QxN (NPN) is normally low, high to activate matrix transistor.
BOARD ID AND S/N
OFF (USB)

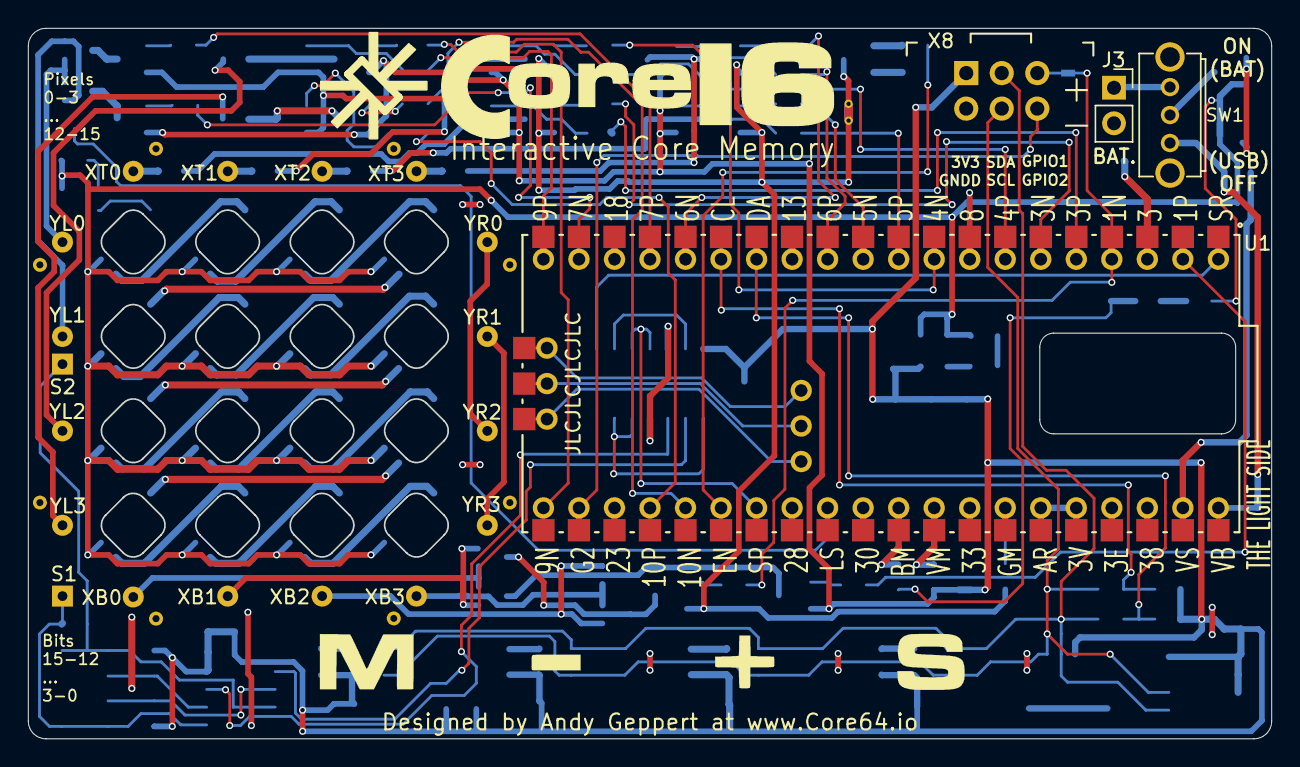
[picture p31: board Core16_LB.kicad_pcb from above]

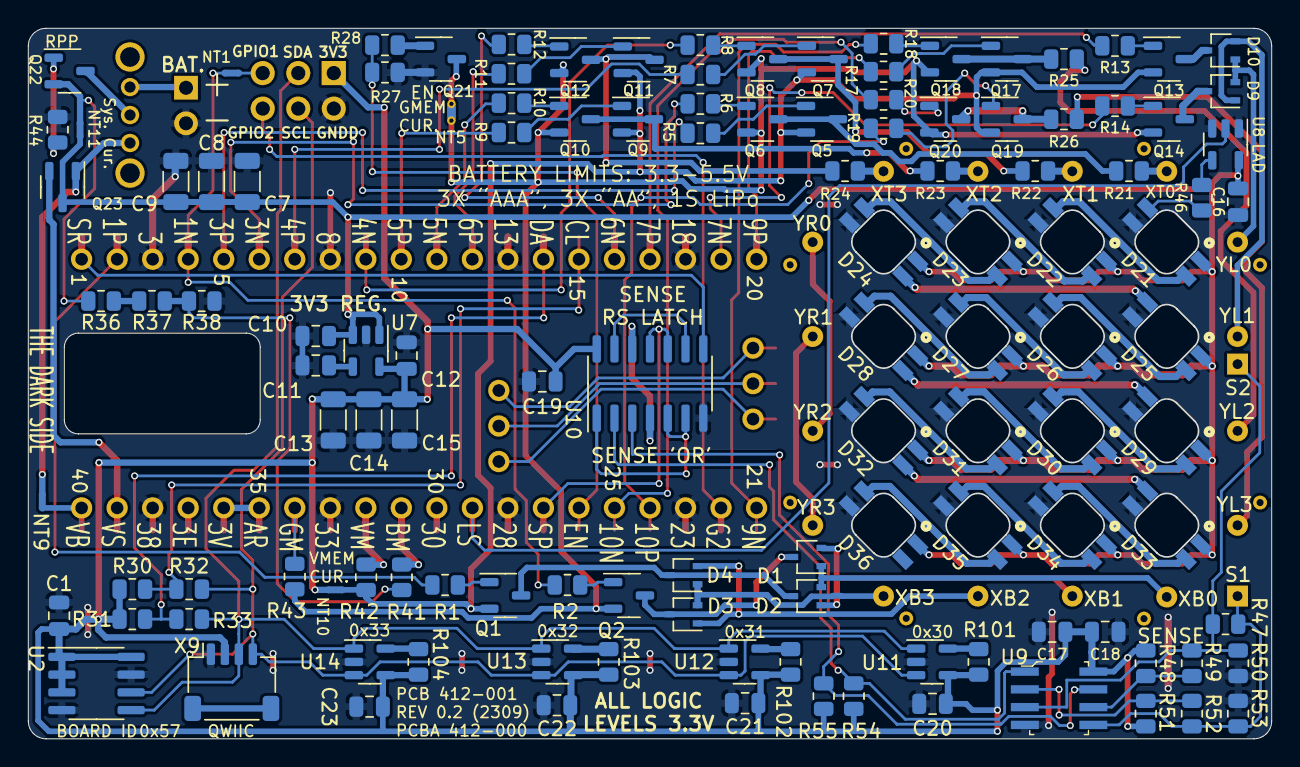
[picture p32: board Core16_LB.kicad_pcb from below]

Board: 2 copper layers, 88.9 x 50.8 mm, 130 parts (107 on the bottom side), 117 nets.

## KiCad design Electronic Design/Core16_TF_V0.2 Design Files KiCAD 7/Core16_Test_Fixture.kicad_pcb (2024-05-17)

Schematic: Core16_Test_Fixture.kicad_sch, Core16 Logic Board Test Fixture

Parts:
C1: 0.1uF; C_0805_2012Metric; LCSC C28233
CM1, CM2: Core_Memory_4x4_Matrix_Front_Facing; core_16_6.75mm_square_front_facing
J1, J2: ALT. BATT.; PinSocket_1x02_P2.54mm_Vertical
J3: Conn_01x18_Socket; PinHeader_1x18_P2.54mm_Vertical
J4, J5: Conn_01x20_Socket; PinHeader_1x20_P2.54mm_Vertical
J6: Conn_01x05_Socket; PinHeader_1x05_P2.54mm_Vertical
J7: Conn_01x06_Socket; PinHeader_1x06_P2.54mm_Vertical
J8: Conn_01x04_Socket; PinHeader_1x04_P2.54mm_Vertical
SW1, SW2: SK12D07L4B; SK12D07VG4; MPN OS102011MA1QN1; LCSC C480340
U1, U2: PICO W; Pico_SC0915_THRUHOLE_CUTOUTS
U3: M24C02-RMN; SOIC-8_3.9x4.9mm_P1.27mm; MPN M24C02-WMN6TP; LCSC C7562
X1, X2: SAO_conn_SFH11-NBPC-D03-ST-BK; Badgelife-SAOv169-BADGE-2x3; MPN SFH11-NBPC-D03-ST-BK
X3: QWIIC; JST_SH_SM04B-SRSS-TB_1x04-1MP_P1.00mm_Horizontal; MPN SM04B-SRSS-TB; LCSC C160404

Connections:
/3V3: C1.1, J7.2, J8.2, U3.2 (E1), U3.3 (E2), U3.8 (VCC), X1.1 (3V3), X2.1 (3V3), X3.2
/3V3_EN: J5.17, U1.37 (3V3_EN), U2.37 (3V3_EN)
/+BATT: J1.1, J2.1, J6.2
/-BATT: J1.2, J2.2, J6.1
/ADC0: J5.11, U1.31 (I2C1_SDA/ADC0/GP26), U2.31 (I2C1_SDA/ADC0/GP26)
/ADC1: J5.12, U1.32 (I2C1_SCL/ADC1/GP27), U2.32 (I2C1_SCL/ADC1/GP27)
/ADC2: J5.14, U1.34 (ADC2/GP28), U2.34 (ADC2/GP28)
/ADC_REF: J5.15, J5.16, U1.35 (ADC_VREF), U1.36 (3V3OUT), U2.35 (ADC_VREF), U2.36 (3V3OUT)
/CM_EN: J5.6, U1.26 (I2C0_SDA/GP20), U2.26 (I2C0_SDA/GP20)
/CM_Q1N: J4.4, U1.4 (I2C1_SDA/SPI0_SCK/GP2), U2.4 (I2C1_SDA/SPI0_SCK/GP2)
/CM_Q1P: J4.2, U1.2 (UART0_RX/I2C0_SCL/GPI0_CSn/GP1), U2.2 (UART0_RX/I2C0_SCL/GPI0_CSn/GP1)
/CM_Q3N: J4.6, U1.6 (UART1_TX/I2C0_SDA/SPI0_RX/GP4), U2.6 (UART1_TX/I2C0_SDA/SPI0_RX/GP4)
/CM_Q3P: J4.5, U1.5 (I2C1_SCL/SPI0_TX/GP3), U2.5 (I2C1_SCL/SPI0_TX/GP3)
/CM_Q4N: J4.9, U1.9 (I2C1_SDA/SPI0_SCK/GP6), U2.9 (I2C1_SDA/SPI0_SCK/GP6)
/CM_Q4P: J4.7, U1.7 (UART1_RX/I2C0_SCL/SPI0_CSn/GP5), U2.7 (UART1_RX/I2C0_SCL/SPI0_CSn/GP5)
/CM_Q5N: J4.11, U1.11 (UART1_TX/I2C0_SDA/SPI1_RX/GP8), U2.11 (UART1_TX/I2C0_SDA/SPI1_RX/GP8)
/CM_Q5P: J4.10, U1.10 (I2C1_SCL/SPI0_TX/GP7), U2.10 (I2C1_SCL/SPI0_TX/GP7)
/CM_Q6N: J4.16, U1.16 (UART0_TX/I2C0_SDA/GPI1_RX/GP12), U2.16 (UART0_TX/I2C0_SDA/GPI1_RX/GP12)
/CM_Q6P: J4.12, U1.12 (UART1_RX/I2C0_SCL/SPI1_CSn/GP9), U2.12 (UART1_RX/I2C0_SCL/SPI1_CSn/GP9)
/CM_Q7N: J4.19, U1.19 (I2C1_SDA/SPI1_SCK/GP14), U2.19 (I2C1_SDA/SPI1_SCK/GP14)
/CM_Q7P: J4.17, U1.17 (UART0_RX/I2C0_SCL/SPI1_CSn/GP13), U2.17 (UART0_RX/I2C0_SCL/SPI1_CSn/GP13)
/CM_Q9N: J5.1, U1.21 (UART0_TX/I2C0_SDA/SPI0_RX/GP16), U2.21 (UART0_TX/I2C0_SDA/SPI0_RX/GP16)
/CM_Q9P: J4.20, U1.20 (I2C1_SCL/SPI1_TX/GP15), U2.20 (I2C1_SCL/SPI1_TX/GP15)
/CM_Q10N: J5.5, U1.25 (I2C1_SCL/SPI0_TX/GP19), U2.25 (I2C1_SCL/SPI0_TX/GP19)
/CM_Q10P: J5.4, U1.24 (I2C1_SDA/SPI0_SCK/GP18), U2.24 (I2C1_SDA/SPI0_SCK/GP18)
/CM_SENSE_1_IN: CM1.17 (S1), CM2.17 (S1), J3.17
/CM_SENSE_2_IN: CM1.18 (S2), CM2.18 (S2), J3.18
/CM_SENSE_PULSE: J5.7, U1.27 (I2C0_SCL/GP21), U2.27 (I2C0_SCL/GP21)
/CM_SENSE_RESET: J4.1, U1.1 (UART0_TX/I2C0_SDA/SPI0_RX/GP0), U2.1 (UART0_TX/I2C0_SDA/SPI0_RX/GP0)
/GPIO1_SAO1: J7.5, X1.5 (GPIO1), X2.5 (GPIO1)
/GPIO2_SAO2: J5.2, J7.6, U1.22 (UART0_RX/I2C0_SCL/SPI0_CSn/GP17), U2.22 (UART0_RX/I2C0_SCL/SPI0_CSn/GP17), X1.6 (GPIO2), X2.6 (GPIO2)
/I2C_3V3_SCL: J7.3, J8.3, U3.6 (SCL), X1.4 (SCL), X2.4 (SCL), X3.4
/I2C_3V3_SDA: J7.4, J8.4, U3.5 (SDA), X1.3 (SDA), X2.3 (SDA), X3.3
/I2C_CLOCK: J4.15, U1.15 (I2C1_SCL/SPI1_TX/GP11), U2.15 (I2C1_SCL/SPI1_TX/GP11)
/I2C_DATA: J4.14, U1.14 (I2C1_SDA/SPI1_SCK/GP10), U2.14 (I2C1_SDA/SPI1_SCK/GP10)
/LED_ARY_3V3_SIG: J5.9, U1.29 (GP22), U2.29 (GP22)
/OFF (USB): J6.5, SW1.1 (A), SW2.1 (A)
/ON_BAT: J6.3, SW1.3 (C), SW2.3 (C)
/PICO_VBUS: J5.20, U1.40 (VBUS), U2.40 (VBUS)
/PICO_VSYS: J5.19, U1.39 (VSYS), U2.39 (VSYS)
/RUN: J5.10, U1.30 (RUN), U2.30 (RUN)
/VSW: J6.4, SW1.2 (B), SW2.2 (B)
/XB0: CM1.12 (XB0), CM2.12 (XB0), J3.5
/XB1: CM1.11 (XB1), CM2.11 (XB1), J3.6
/XB2: CM1.10 (XB2), CM2.10 (XB2), J3.7
/XB3: CM1.9 (XB3), CM2.9 (XB3), J3.8
/XT0: CM1.1 (XT0), CM2.1 (XT0), J3.1
/XT1: CM1.2 (XT1), CM2.2 (XT1), J3.2
/XT2: CM1.3 (XT2), CM2.3 (XT2), J3.3
/XT3: CM1.4 (XT3), CM2.4 (XT3), J3.4
/YL0: CM1.16 (YL0), CM2.16 (YL0), J3.9
/YL1: CM1.15 (YL1), CM2.15 (YL1), J3.10
/YL2: CM1.14 (YL2), CM2.14 (YL2), J3.11
/YL3: CM1.13 (YL3), CM2.13 (YL3), J3.12
/YR0: CM1.5 (YR0), CM2.5 (YR0), J3.13
/YR1: CM1.6 (YR1), CM2.6 (YR1), J3.14
/YR2: CM1.7 (YR2), CM2.7 (YR2), J3.15
/YR3: CM1.8 (YR3), CM2.8 (YR3), J3.16
GNDD: C1.2, J4.3, J4.8, J4.13, J4.18, J5.3, J5.8, J5.13, J5.18, J7.1, J8.1, U1.3 (GND), U1.8 (GND), U1.13 (GND), U1.18 (GND), U1.23 (GND), U1.28 (GND), U1.33 (AGND/GND), U1.38 (GND), U2.3 (GND), U2.8 (GND), U2.13 (GND), U2.18 (GND), U2.23 (GND), U2.28 (GND), U2.33 (AGND/GND), U2.38 (GND), U3.1 (E0), U3.4 (VSS), U3.7 (~WC), X1.2 (GND), X2.2 (GND), X3.1

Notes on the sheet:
INCLUDED:
AMBIENT PROX. SENSOR OLED AND!XOR IO Exp. MCP23017 AND!XOR EEPROM AT24C32r NFC CLICK PN7120
TEST CIRCUIT
SAO
I2C ADDRESS TABLE
Pico has incoming USB power/programming on board.
TEST EEPROM
EEPROM I2C ADDRESS: 0b1010110, 0x56 (86)
CORE TEST
Generic 0.96” (128x64) or 1.5” (128x128) I2C 4-pins, often ADDRESS: 0x3C (60 decimal) Alternate is 0x3D, not 0x7A or 0x78 (wrong 8-bit)!
DUT
CORE MATRIX
PICO
0x29 (47) 0x30 (48) 0x31 (49) 0x32 (50) 0x33 (51) 0x57 (87) 0x56 (86)
OLED
POWER
PICO 21-40
POWER TEST
SYSTEM GROUND
Connect via SAO.
I2C ADDRESS TABLE
AMBIENT LIGHT SENSOR HALL SENSOR 1 HALL SENSOR 2 HALL SENSOR 3 HALL SENSOR 4 EEPROM (BOARD ID) EEPROM (TEST FIXTURE)
PICO 1-20
0x38 (56) 0x3C (60) 0x20 (32) 0x50 (80) 0x50-53
QWIIC I2C
I2C GPIO
OPTIONAL:
All 7-bit addresses should be greater than 0x07 and less than 0x78 (120).
OLED MONOCHROME I2C
DIGITAL LOGIC GROUND PLANE

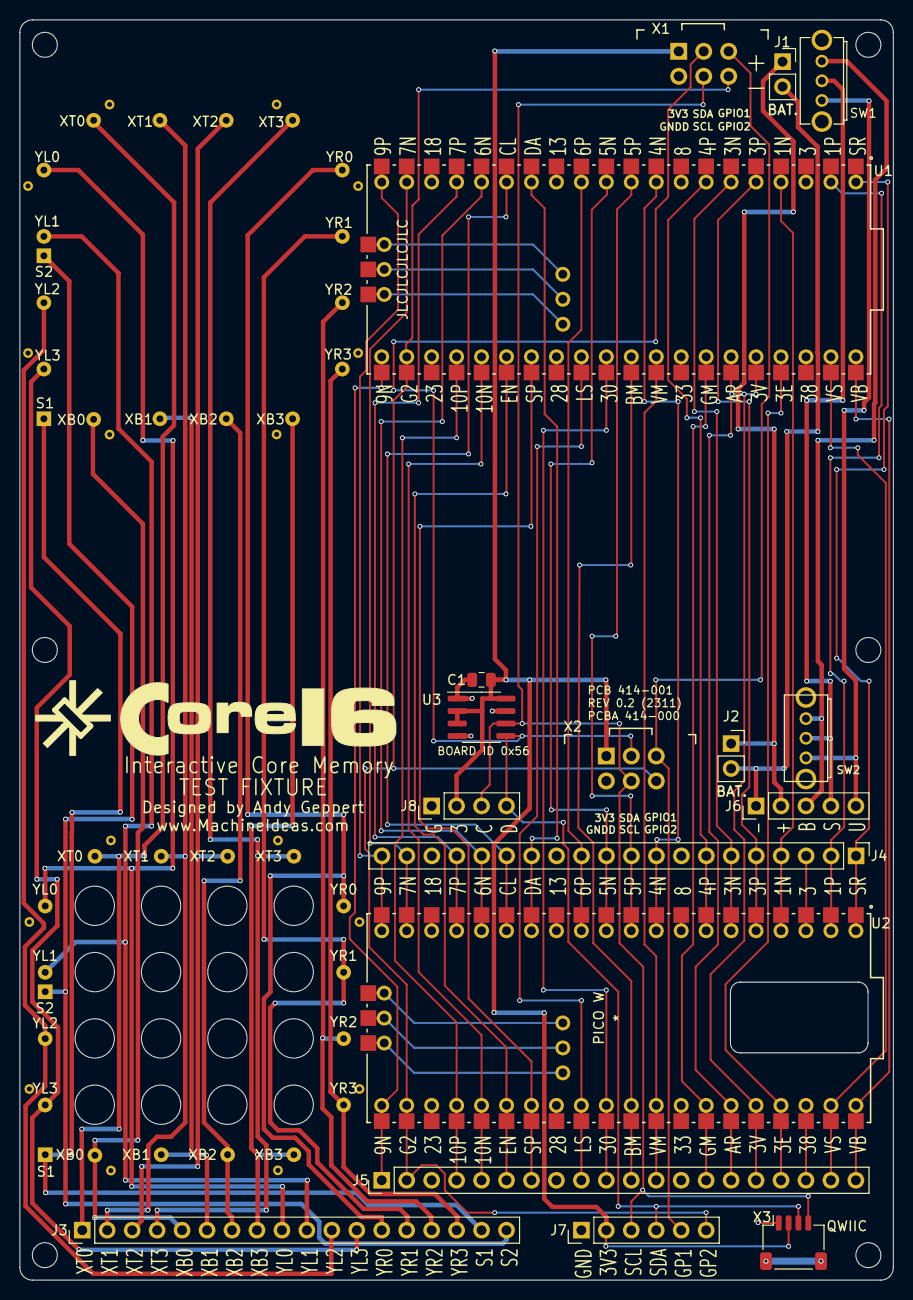
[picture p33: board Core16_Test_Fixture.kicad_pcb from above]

Board: 2 copper layers, 88.9 x 128.3 mm, 20 parts (0 on the bottom side), 59 nets.

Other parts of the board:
L1: Core_64_Logo; Core16_w_core_symbol

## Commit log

2024-08-11 Organize documentation, add board render images
2024-08-23 Update .gitignore, remove .DS_Store
    [Core16_BOM.csv, Core16_LB-bottom.csv, Core16_LB_BOM.csv]

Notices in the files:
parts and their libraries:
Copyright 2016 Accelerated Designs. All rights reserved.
